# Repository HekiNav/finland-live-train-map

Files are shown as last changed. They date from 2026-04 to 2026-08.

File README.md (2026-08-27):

# Finland live train map

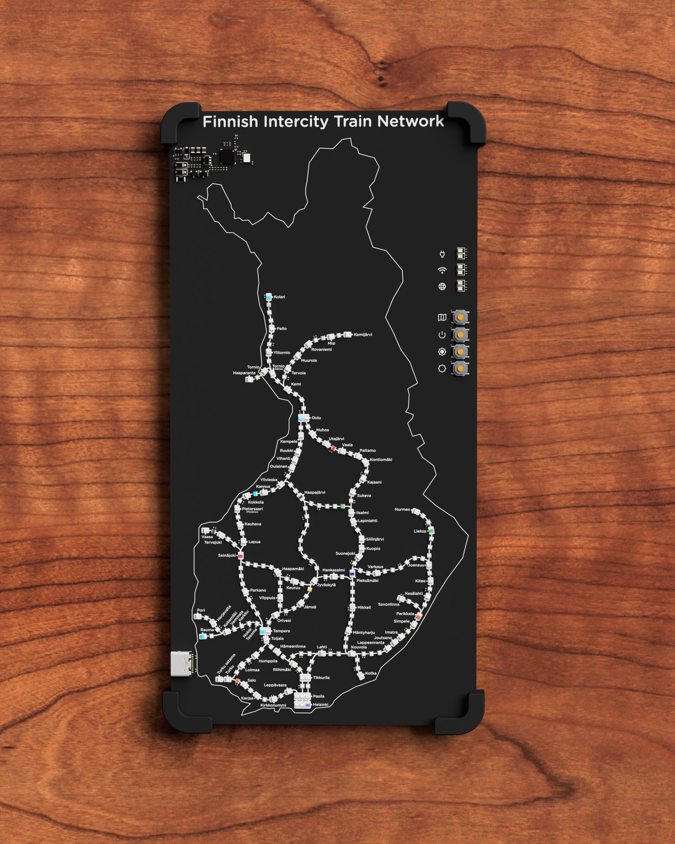
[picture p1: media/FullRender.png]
3dRender


The project consist of the physical pcb and case as well as the server that processes the information from the api and serves it to the ESP-32 to process. The physical project is a pcb with LEDs marking the route for intercity trains across Finland. There are two versions of the map. A more simplified version with just the routes visible. Then there is the more geografically correct version with the borders of Finland printed on the silkscreen. The LEDs mark the position of trains in real time so you can see at a glance where the trains are. The case makes it possible to wall mount the pcb or have it on your desk.

This project was made for Hack Club [Fallout](https://fallout.hackclub.com) by [NoseFa](https://github.com/NoseFa) and [Hekinav](https://github.com/HekiNav).

## Repository structure / table of contents

NOTE! All software has been moved to [another repo (HekiNav/ltm-firmware)](https://github.com/HekiNav/ltm-firmware)

**Each directory contains its own README file with more detailed information on the specific section. Basic information is provided here.**

### [`/pcb`](./pcb/README.md)
Contains KiCad design files
View interactive PCB design in [KiCanvas](https://kicanvas.org/?github=https%3A%2F%2Fgithub.com%2FHekinav%2FFinland-Live-Train-Map%2Ftree%2Fmain%2Fpcb)

### [`/design`](./design/README.md)
Contains Map Design ideas and plans as Inkscape SVGs

### [`/server`](https://github.com/HekiNav/ltm-firmware/tree/main/server/README.md)
Contains the NodeJS server that processes data from Fintraffic to amore usable format

### [`/firmware`](https://github.com/HekiNav/ltm-firmware/tree/main/firmware/README.md)
Contains the Platformio firmware for the ESP32C3

### [BuildGuide.md](BuildGuide.md)
Contains instructions for building the project.

## Why this exists

This project was made because we wanted to work on something together and Hack Club was running the Fallout event. Hekinav has built a similar type of project before for Helsinki. [The Helsinki Live Train map](https://github.com/HekiNav/helsinki-live-train-map) and we decided that making one of all the Trains in Finland would be cool. This project is meant to be something to look at and something cool to have in your space. Thats why we put so much effort in the silkscreen of the pcb and the placement of the LED's. We wanted it to be good to look at.

## BOM

The BOM for this project is pretty much just making buying the PCB and then 3d printing the case (we are self-printing so we didn't add this). You can see the JLCPCB formatted [BOM.csv](./pcb/jlcpcb/production_files/BOM-fin-ltm.csv). We have some more detailed information about how to order it. Here is also a table that just includes the price of the PCB and the assembly, shipping + customs for it.

| Part | Total price | Link | Extra info  | 
| --- | --- | --- | --- |
| PCB | 14.83€ | [JLCPCB](https://jlcpcb.com/pcb-fabrication/fr4-pcb)| |
| PCBA inc. components  | 136.03€ | [JLCPCB PCBA](https://jlcpcb.com/pcb-assembly) | For specific component pricing see the JLCPCB bom in the pcb folder  |
| JLCPCB shipping | 22.37€ | [Shipping](https://jlcpcb.com/shipping) | |
| Taxes / customs fees  | 44.18€ | [Tulli.fi](https://tulli.fi/tullilaskuri#/) | |
| | | | |
| Total | 217.42€ | | |

## Zine page

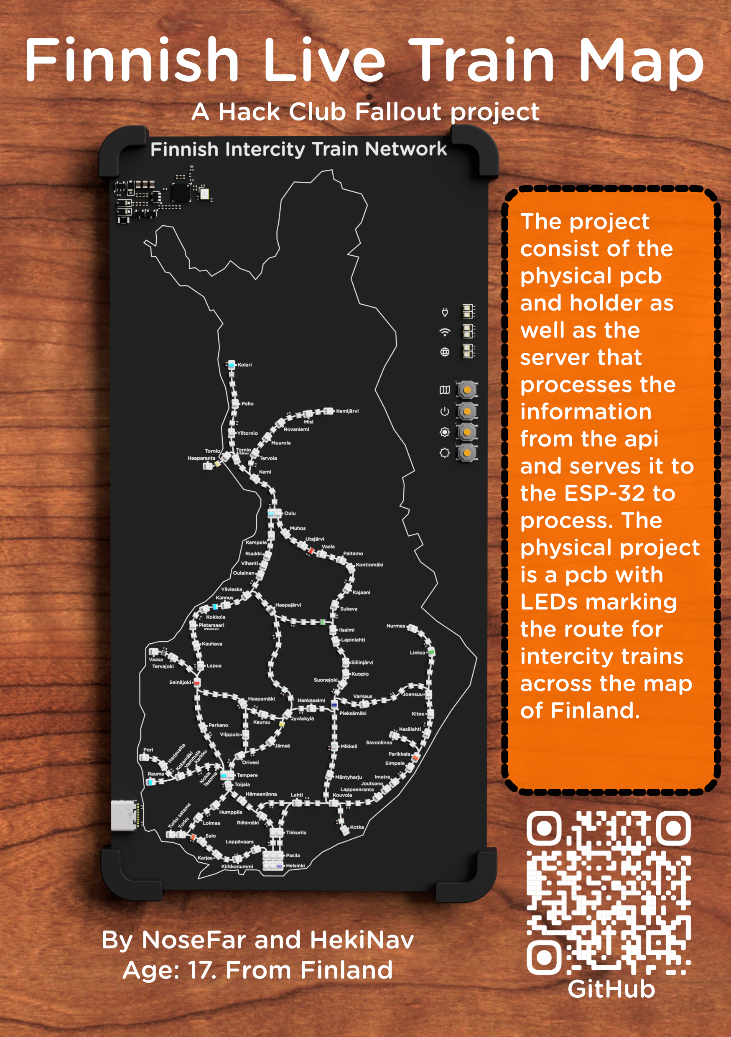
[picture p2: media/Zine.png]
Zine Page


We were required to make a Zine page for Fallout. Available as a [`zine.pdf`](Zine.pdf)

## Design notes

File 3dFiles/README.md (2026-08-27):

# 3D design

This section includes all the 3D models for the project. Including files for the full 3d project, ready to print files and the 3d files for the PCB. The [`/printable`](./Printable/) folder includes ready to print files and the [`/FullProject`](./FullProject/) folder includes the full Fusion project files including the PCB, holder etc.

## Design choices

We wanted the holder to be as simple as possible and not take away from the main piece which is the PCB and the map on it. We wanted the holder to cover as little as possible while still being secure and holding the PCB well. We also didn't want any screws on the pcb at all so the case was designed to fit these criteria. The PCB is held in slots and no screws are used. On the front side the holder only covers small areas in each corner so the PCB stays very visible. We also plan to print it in a black filament which makes it blend in with the PCB better. Currently there is a wall mounted version that has a similar hole that is used for mounting picture frames on the wall. 

3dRender

The case is printed in 3 seperate pieces. The main body and then the top corners that are seperate pieces that slot into the main frame when mounting. So print the main frame in one piece and then slot in the PCB to it and then finally add the top corners to make the holder more secure and look better. 

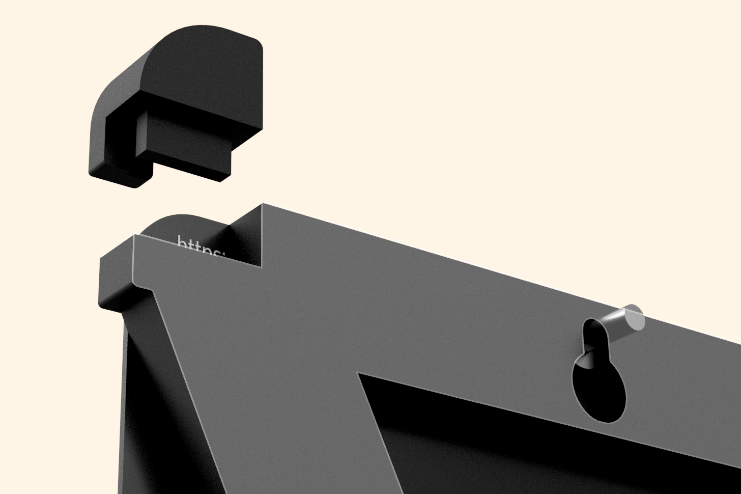
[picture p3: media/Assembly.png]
render assembly


Here is a picture of the frame seperated. 

## The kickstand

The full fusion project includes a lot of random history and a kickstanc section. This is because we were planning on adding a kickstand to the design but ended up not having time for it. The project history is kind of a mess because of this. The part does work and is done but the kickstand will be included in a later design version.

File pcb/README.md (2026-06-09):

[Back to main page](https://github.com/HekiNav/finland-live-train-map/tree/main)
# PCB Design

- Made in KiCad with [CDFER's JLCPCB KiCad library](https://github.com/CDFER/JLCPCB-Kicad-Library).
- Inspiration for antenna and power system taken from [CDFER's live train maps](https://keastudios.co.nz). They are very cool!
- Designed to be fabricated and assembled by JLCPCB
    - PCBA by JLC because tiny components and hundreds of leds are hard to assemble manually. Also, LCSC components are very cheap with JLC.

## Main components

- ESP32-C3FH4 (chip)
    - 4MiB built-in flash
- Level Shifter (3V3 data from esp to 5V led data)
    - [TI SN74LV1T34DBVR](https://www.lcsc.com/product-detail/C100024.html)
- Power management
    - USB VBUS to 5V and 3V3 rails
    - Mosfet to shut down 5V rail
- 239 ARGB LEDs: [Xinglight XL-1615RGBC-2812B-S](https://www.lcsc.com/product-detail/C41413180.html)
    - The -S version is less bright and cheaper than the non -S version. 
    - These LEDs are a cheaper alternative (knockoff) to WorldSemi WS2812Bs

### KiCanvas viewer

View interactive PCB design in [KiCanvas](https://kicanvas.org/?github=https%3A%2F%2Fgithub.com%2FHekinav%2FFinland-Live-Train-Map%2Ftree%2Fmain%2Fpcb)

**NOTICE**: KiCanvas does not properly render everything, plase hide layers User.1-User.5 to view power circuitry

## Schematic

Schematic image

Some of the LEDs are missing because they were removed after making the initial layout
Schematic image

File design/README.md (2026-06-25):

[Back to main page](https://github.com/HekiNav/finland-live-train-map/tree/main)

# Map layout design

The layout of the map can be geographical or graphical
The SVGs in this directory are Inkscape SVGs

## Two options for map

### Geographical

`GeographicalMap.svg`

- Geographically accurate
- Recognisable
- Some distances between stations very short/long

### Graphical

`graph_v1.svg`

- More compact, saves on PCB costs
- Distances between stations more equal.

## Techical design

`TrainMapSignal.svg`

- Technical design and plans

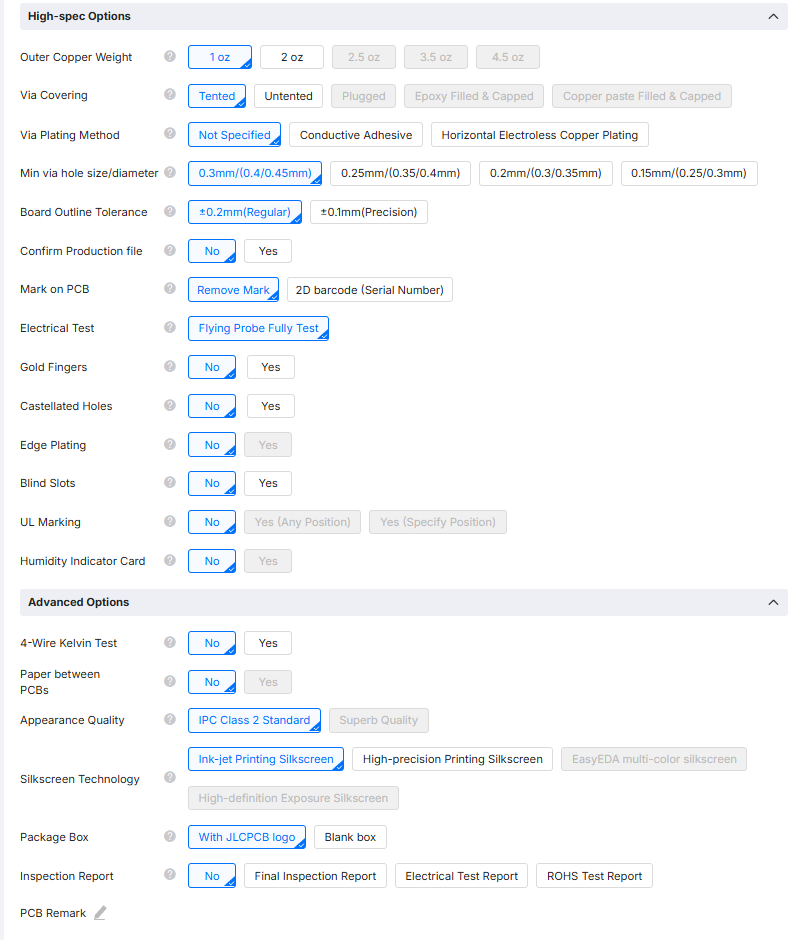
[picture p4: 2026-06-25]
media/JLCPCB/HighSpecOptions.png

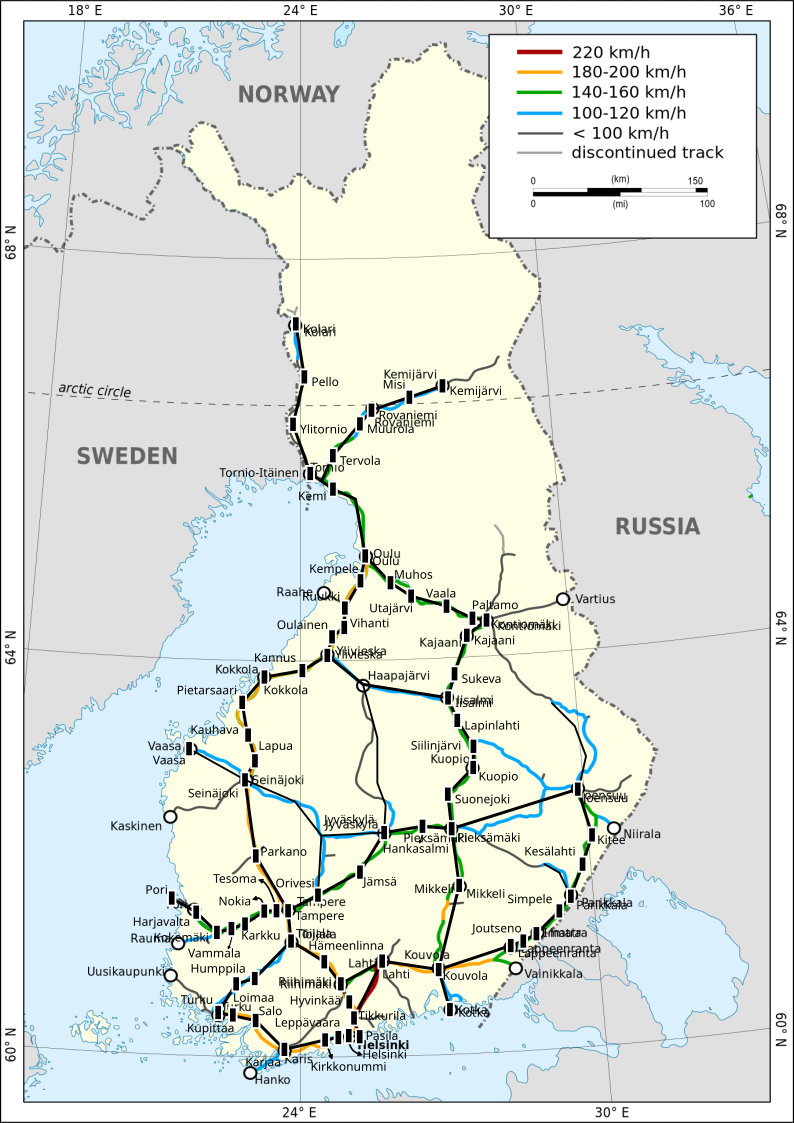
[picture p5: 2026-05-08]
design/GeographicalMap.png

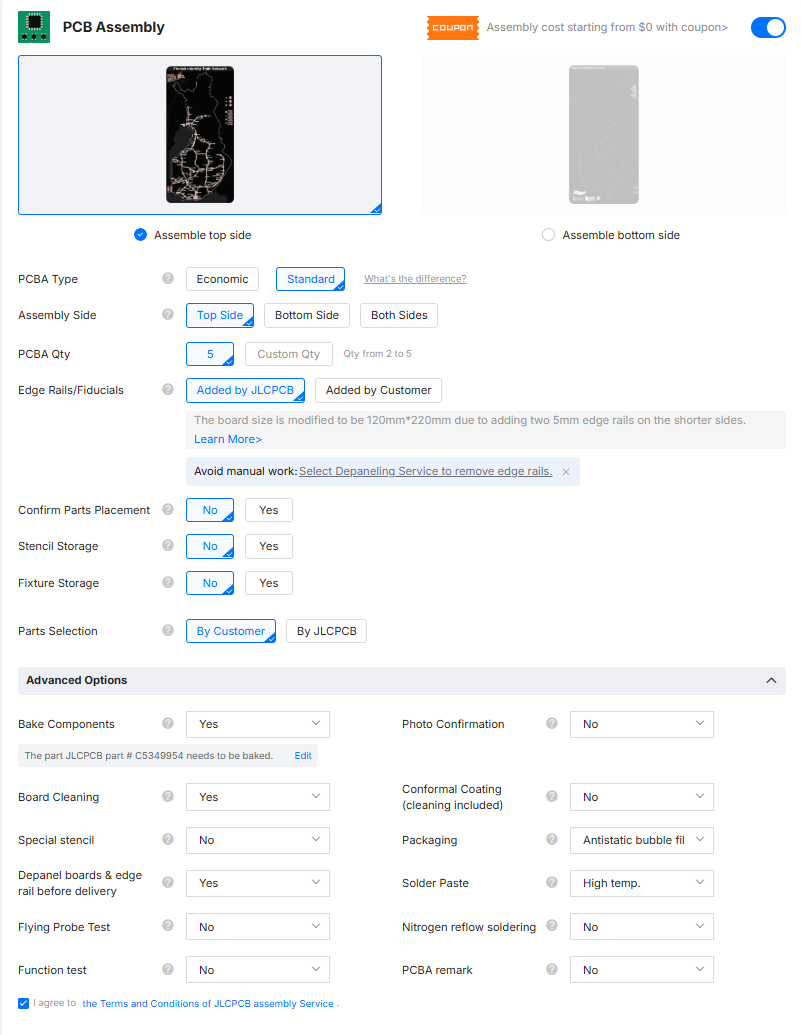
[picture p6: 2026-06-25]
media/JLCPCB/PCBAoptions.png

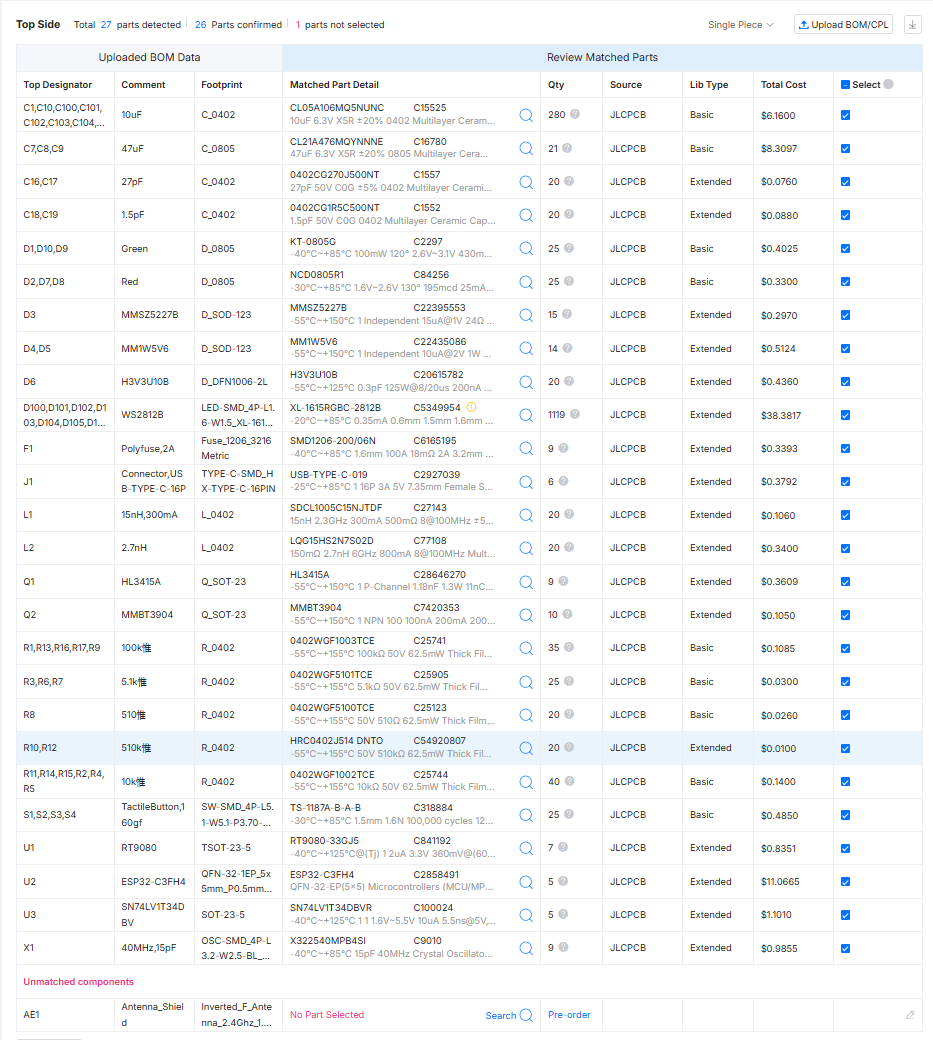
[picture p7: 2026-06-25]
media/JLCPCB/BOMOptions.png

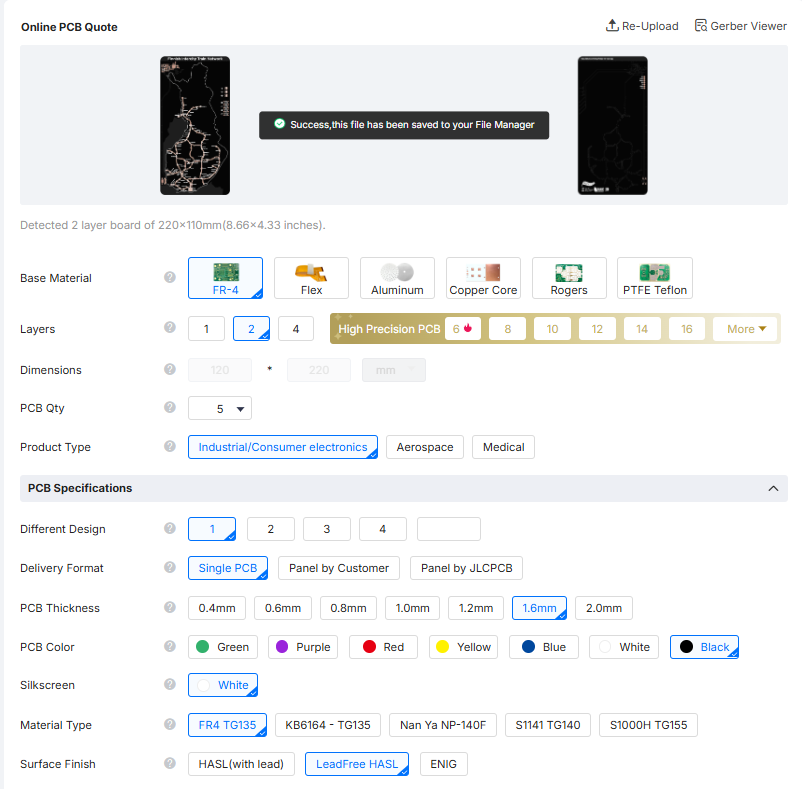
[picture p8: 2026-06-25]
media/JLCPCB/BasicPcbOptions.png

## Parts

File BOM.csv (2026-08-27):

Part | Quantity | Total price | Links | Extra info | LCSC id
PCB | 5 | 14.84€ | https://jlcpcb.com/pcb-fabrication/fr4-pcb
PCBA inc. components | 5 | 136.03€ | https://jlcpcb.com/pcb-assembly | For specific component pricing see the JLCPCB bom in the pcb folder
JLCPCB shipping (UPS) | 1 | 22.37€ | https://jlcpcb.com/shipping
Import tax / customs | 1 | 44.18€ | https://tulli.fi/tullilaskuri#/
1.5pF | 20 | 0.18€ | https://jlcpcb.com/partdetail/1904-0402CG1R5C500NT/C1552 |  | C1552
100kΩ | 35 | 0.11€ | https://jlcpcb.com/partdetail/26484-0402WGF1003TCE/C25741 |  | C25741
10kΩ | 40 | 0.14€ | https://jlcpcb.com/partdetail/26487-0402WGF1002TCE/C25744 |  | C25744
10uF | 280 | 9.97€ | https://jlcpcb.com/partdetail/16204-CL05A106MQ5NUNC/C15525 |  | C15525
15nH,300mA | 20 | 0.11€ | https://jlcpcb.com/partdetail/Sunlord-SDCL1005C15NJTDF/C27143 |  | C27143
2.7nH | 20 | 0.30€ | https://jlcpcb.com/partdetail/MurataElectronics-LQG15HS2N7S02D/C77108 |  | C77108
27pF | 20 | 0.09€ | https://jlcpcb.com/partdetail/1909-0402CG270J500NT/C1557 |  | C1557
40MHz, 15pF | 9 | 0.86€ | https://jlcpcb.com/partdetail/YXC_CrystalOscillators-X322540MPB4SI/C9010 |  | C9010
47uF | 21 | 3.67€ | https://jlcpcb.com/partdetail/17464-CL21A476MQYNNNE/C16780 |  | C16780
5.1kΩ | 25 | 0.03€ | https://jlcpcb.com/partdetail/26648-0402WGF5101TCE/C25905 |  | C25905
510kΩ | 20 | 0.01€ | https://jlcpcb.com/partdetail/HWACHN-HRC0402J514DNTO/C54920807 |  | C54920807
510Ω | 20 | 0.04€ | https://jlcpcb.com/parts/componentSearch?searchTxt=C25123 |  | C25123
Connector, USB-TYPE-C-16P | 6 | 0.33€ | https://jlcpcb.com/partdetail/DEALON-USB_TYPE_C019/C2927039 |  | C2927039
ESP32-C3FH4 | 5 | 9.44€ | https://jlcpcb.com/parts/componentSearch?searchTxt=C2858491 |  | C2858491
Discrete Diode Emerald Green Water Clear 0805 LED Indication | 25 | 0.35€ | https://jlcpcb.com/parts/componentSearch?searchTxt=C2297 |  | C2297
H3V3U10B | 20 | 0.60€ | https://jlcpcb.com/partdetail/hongjiacheng-H3V3U10B/C20615782 |  | C20615782
HL3415A | 9 | 0.32€ | https://jlcpcb.com/partdetail/hongjiacheng-HL3415A/C28646270 |  | C28646270
MM1W5V6 | 14 | 0.68€ | https://jlcpcb.com/partdetail/hongjiacheng-MM1W5V6/C22435086 |  | C22435086
MMBT3904 | 10 | 0.10€ | https://jlcpcb.com/partdetail/hongjiacheng-MMBT3904/C7420353 |  | C7420353
MMSZ5227B | 15 | 0.26€ | https://jlcpcb.com/partdetail/hongjiacheng-MMSZ5227B/C22395553 |  | C22395553
Polyfuse, 2A | 9 | 0.32€ | https://jlcpcb.com/partdetail/BORN-SMD1206_20006N/C6165195 |  | C6165195
Red | 25 | 0.29€ | https://jlcpcb.com/partdetail/85425-NCD0805R1/C84256 |  | C84256
SN74LV1T34DBV | 5 | 0.95€ | https://jlcpcb.com/partdetail/TexasInstruments-SN74LV1T34DBVR/C100024 |  | C100024
Tactile Button, 160gf | 25 | 0.44€ | https://jlcpcb.com/partdetail/XKBConnection-TS_1187A_B_AB/C318884 |  | C318884
WS2812B | 1119 | 33.71€ | https://jlcpcb.com/partdetail/XINGLIGHT-XL_1615RGBC2812B/C5349954 |  | C5349954
RT9080 | 7 | 0.73€ | https://jlcpcb.com/partdetail/RichtekTech-RT908033GJ5/C841192 |  | C841192
Total: |  | 281.46€

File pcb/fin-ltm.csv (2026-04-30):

Reference | Qty | Value | DNP | Exclude from BOM | Exclude from Board | Footprint | Datasheet | Class | LCSC
AE1 | 1 | Antenna_Shield |  |  |  |  | ~
C1,C2,C3,C4,C5,C6,C7,C11,C12,C13,C18,C19,C20,C21,C22 | 15 | 10uF |  |  |  | PCM_JLCPCB:C_0402 | https://www.lcsc.com/datasheet/lcsc_datasheet_2208231630_Samsung-Electro-Mechanics-CL05A106MQ5NUNC_C15525.pdf | Basic Component | C15525
C8,C9,C10 | 3 | 47uF |  |  |  | PCM_JLCPCB:C_0805 | https://www.lcsc.com/datasheet/lcsc_datasheet_2304140030_Samsung-Electro-Mechanics-CL21A476MQYNNNE_C16780.pdf | Basic Component | C16780
C14,C15 | 2 | 27pF |  |  |  | PCM_JLCPCB:C_0402 | https://www.lcsc.com/datasheet/lcsc_datasheet_2304140030_FH--Guangdong-Fenghua-Advanced-Tech-0402CG270J500NT_C1557.pdf | Preferred Component | C1557
C16,C17 | 2 | 1.5pF |  |  |  | PCM_JLCPCB:C_0402 | https://www.lcsc.com/datasheet/lcsc_datasheet_2304140030_FH--Guangdong-Fenghua-Advanced-Tech-0402CG1R5C500NT_C1552.pdf | Preferred Component | C1552
D1,D7,D9 | 3 | Red |  |  |  | PCM_JLCPCB:D_0805 | https://www.lcsc.com/datasheet/lcsc_datasheet_2409272203_Foshan-NationStar-Optoelectronics-NCD0805R1_C84256.pdf | Basic Component | C84256
D2,D4 | 2 | MM1W5V6 |  |  |  | PCM_JLCPCB:D_SOD-123 | https://wmsc.lcsc.com/wmsc/upload/file/pdf/v2/lcsc/2405210914_hongjiacheng-MM1W5V6_C22435086.pdf | Preferred Component | C22435086
D3 | 1 | MMSZ5227B |  |  |  | PCM_JLCPCB:D_SOD-123 | https://wmsc.lcsc.com/wmsc/upload/file/pdf/v2/lcsc/2405091603_hongjiacheng-MMSZ5227B_C22395553.pdf | Preferred Component | C22395553
D5,D8,D10 | 3 | Green |  |  |  | PCM_JLCPCB:D_0805 | https://www.lcsc.com/datasheet/lcsc_datasheet_1806151820_Hubei-KENTO-Elec-KT-0805G_C2297.pdf | Basic Component | C2297
D6 | 1 | H3V3U10B |  |  |  | PCM_JLCPCB:D_DFN1006-2L | https://wmsc.lcsc.com/wmsc/upload/file/pdf/v2/lcsc/2401261524_hongjiacheng-H3V3U10B_C20615782.pdf | Preferred Component | C20615782
F1 | 1 | Polyfuse, 2A |  |  |  | Fuse:Fuse_1206_3216Metric | ~ |  | C6165195
J1 | 1 | Connector, USB-TYPE-C-16P |  |  |  | PCM_JLCPCB:TYPE-C-SMD_HX-TYPE-C-16PIN | https://atta.szlcsc.com/upload/public/pdf/source/20220920/0EF8F885FCCEA71F60E9E85152155021.pdf |  | C2927039
J2 | 1 | Test Connector |  | Excluded from BOM
J3 | 1 | Display |  | Excluded from BOM
L1 | 1 | 15nH,300mA |  |  |  | PCM_JLCPCB:L_0402 | https://www.lcsc.com/datasheet/lcsc_datasheet_2310301641_Sunlord-SDCL1005C15NJTDF_C27143.pdf | Preferred Component | C27143
L2 | 1 | 2.7nH |  |  |  | PCM_JLCPCB:L_0402 | ~ |  | C77108
Q1 | 1 | MMBT3904 |  |  |  | PCM_JLCPCB:Q_SOT-23 | https://wmsc.lcsc.com/wmsc/upload/file/pdf/v2/lcsc/2312221203_hongjiacheng-MMBT3904_C7420353.pdf | Preferred Component | C7420353
Q2 | 1 | HL3415A |  |  |  | PCM_JLCPCB:Q_SOT-23 | https://wmsc.lcsc.com/wmsc/upload/file/pdf/v2/lcsc/2407121622_hongjiacheng-HL3415A_C28646270.pdf | Preferred Component | C28646270
R1,R2,R10 | 3 | 5.1kΩ |  |  |  | PCM_JLCPCB:R_0402 | https://www.lcsc.com/datasheet/lcsc_datasheet_2206010045_UNI-ROYAL-Uniroyal-Elec-0402WGF5101TCE_C25905.pdf | Basic Component | C25905
R3,R5,R9,R12,R14,R16,R17,R18,R19 | 9 | 10kΩ |  |  |  | PCM_JLCPCB:R_0402 | https://www.lcsc.com/datasheet/lcsc_datasheet_2411221126_UNI-ROYAL-Uniroyal-Elec-0402WGF1002TCE_C25744.pdf | Basic Component | C25744
R4,R8 | 2 | 510kΩ |  |  |  | PCM_JLCPCB:R_0402 | https://www.lcsc.com/datasheet/lcsc_datasheet_2206010216_UNI-ROYAL-Uniroyal-Elec-0402WGF5103TCE_C11616.pdf | Preferred Component | C11616
R6,R7,R13,R15 | 4 | 100kΩ |  |  |  | PCM_JLCPCB:R_0402 | https://www.lcsc.com/datasheet/lcsc_datasheet_2206010100_UNI-ROYAL-Uniroyal-Elec-0402WGF1003TCE_C25741.pdf | Basic Component | C25741
R11 | 1 | 510Ω |  |  |  | PCM_JLCPCB:R_0402 | https://www.lcsc.com/datasheet/lcsc_datasheet_2205311900_UNI-ROYAL-Uniroyal-Elec-0402WGF5100TCE_C25123.pdf | Basic Component | C25123
S1,S2,S3,S4 | 4 | Tactile Button, 160gf |  |  |  | PCM_JLCPCB:SW-SMD_4P-L5.1-W5.1-P3.70-LS6.5-TL-2 | https://www.lcsc.com/datasheet/lcsc_datasheet_2304140030_XKB-Connection-TS-1187A-B-A-B_C318884.pdf | Basic Component | C318884
U1 | 1 | ESP32-C3FH4 |  |  |  | PCM_JLCPCB:QFN-32-1EP_5x5mm_P0.5mm_EP3.7x3.7mm_ThermalVias | https://www.espressif.com/sites/default/files/documentation/esp32-c3_datasheet_en.pdf |  | C2858491
U2 | 1 | RT9080 |  |  |  | Package_TO_SOT_SMD:TSOT-23-5 |  |  | C841192
U3 | 1 | SN74LV1T34DBV |  |  |  | Package_TO_SOT_SMD:SOT-23-5 | https://www.ti.com/lit/ds/symlink/sn74lv1t34.pdf |  | C100024
X1 | 1 | 40MHz, 15pF |  |  |  | PCM_JLCPCB:OSC-SMD_4P-L3.2-W2.5-BL_SIT8008BI | https://www.lcsc.com/datasheet/lcsc_datasheet_2403291504_YXC-Crystal-Oscillators-X322540MPB4SI_C9010.pdf |  | C9010

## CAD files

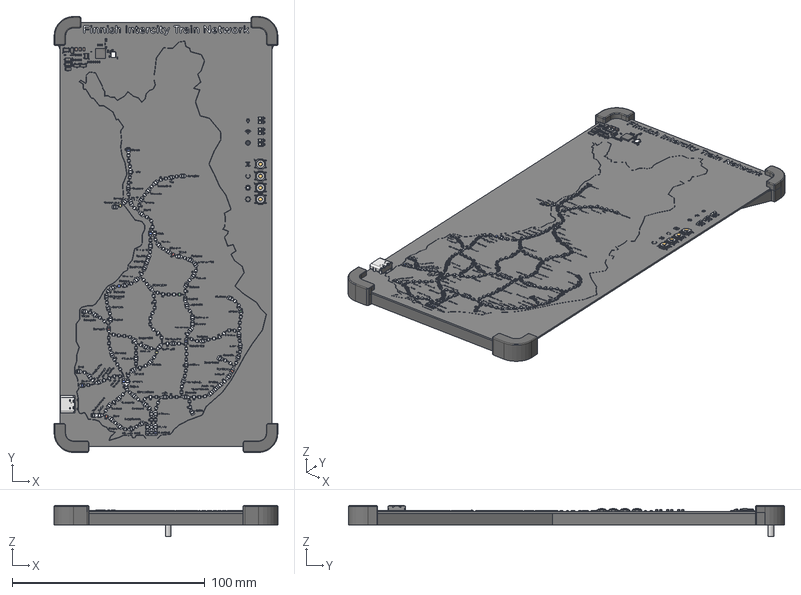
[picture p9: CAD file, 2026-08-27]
3dFiles/FullProject/FullProject.step
116.0 x 226.0 x 16.1 mm
零件26 x 223
R_0402_1005Metric x 17
C_0402_1005Metric x 58
SW_SPST_TL3342 x 4
LED_0805_2012Metric_Castellated x 6
Fuse_1206_3216Metric_1
SOT_23 x 2
C_0805_2012Metric x 3
QFN-32-1EP_5x5mm_Pitch0.5mm
D_SOD_123 x 3
OSC-SMD_4P-L3.2-W2.5-CJ13-320001210A20
DFN1006_L1-W0.6-H0.4-2L-RD
TYPE-C-SMD_HX-TYPE-C-16PIN_1
L_0402_1005Metric x 2
SOT-23-5_1
TSOT-23-5_1
fin-ltm_silkscreen
fin-ltm_silkscreen_1
fin-ltm_PCB
FinnishTrainProject
BHS JIS B 1111 - M3x8 Steel 4.6 Plain

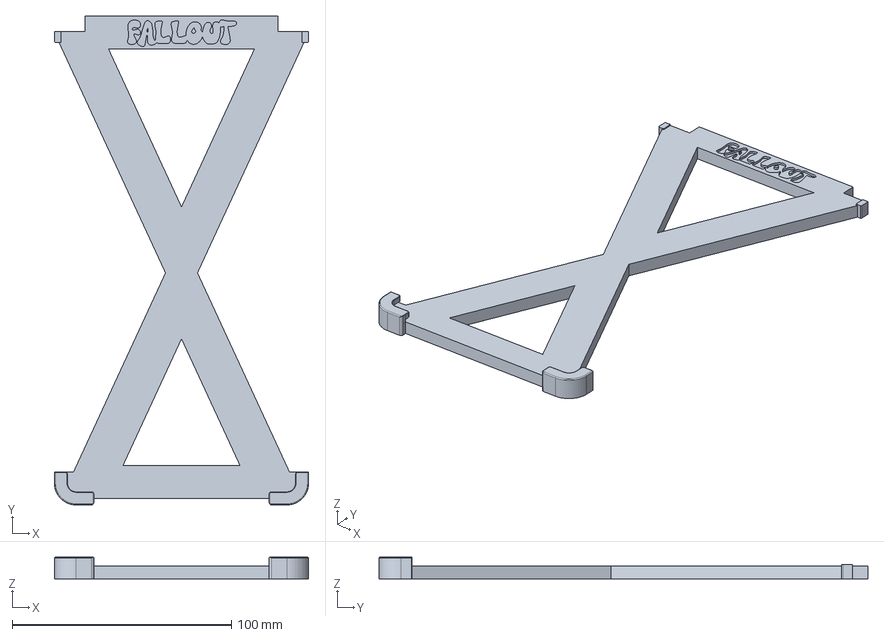
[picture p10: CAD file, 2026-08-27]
3dFiles/Printable/WallMount/WallmountMainBody.step
116.0 x 223.0 x 10.0 mm

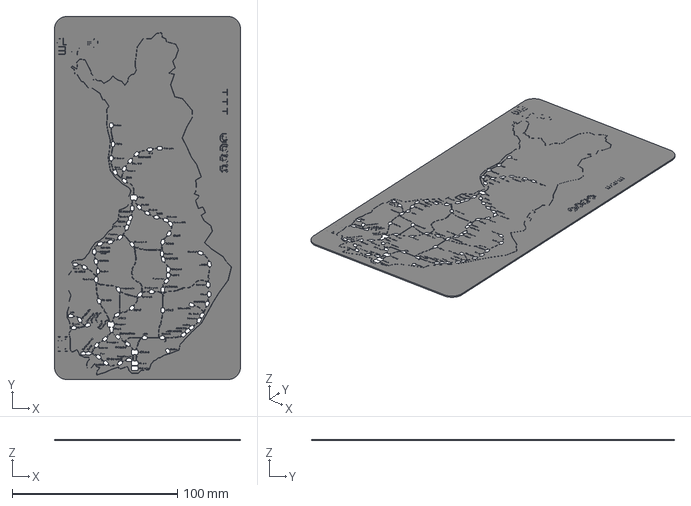
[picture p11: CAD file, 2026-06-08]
3dFiles/PCB/OnlyPcb.step
112.5 x 219.5 x 0.975 mm
fin-ltm_silkscreen x 2
fin-ltm_PCB

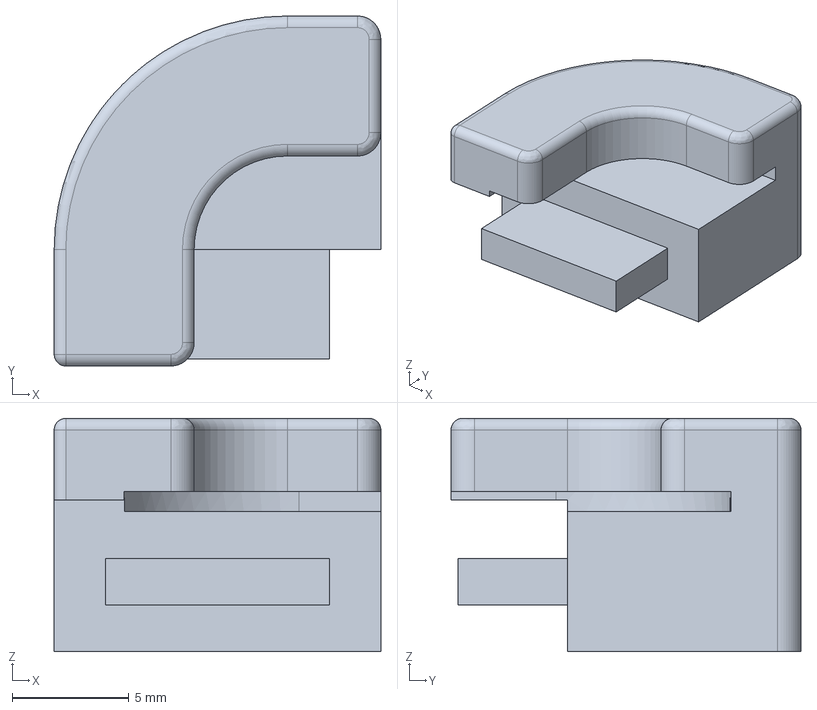
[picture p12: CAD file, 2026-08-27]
3dFiles/Printable/WallMount/WallMountTopLeft.step
14.0 x 15.0 x 10.0 mm

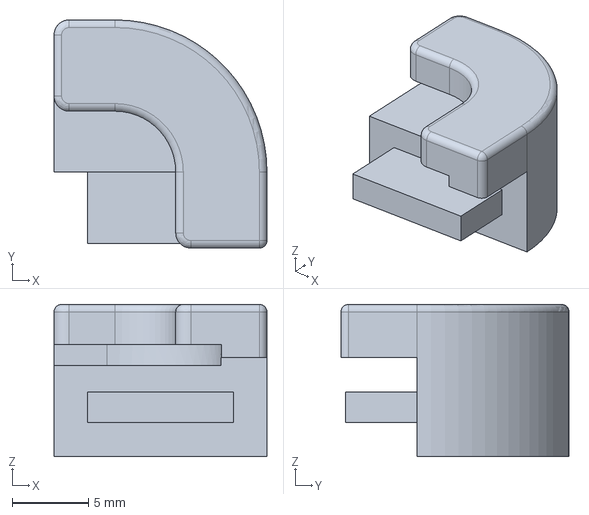
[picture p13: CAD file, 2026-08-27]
3dFiles/Printable/WallMount/WallMountTopRight.step
14.0 x 15.0 x 10.0 mm

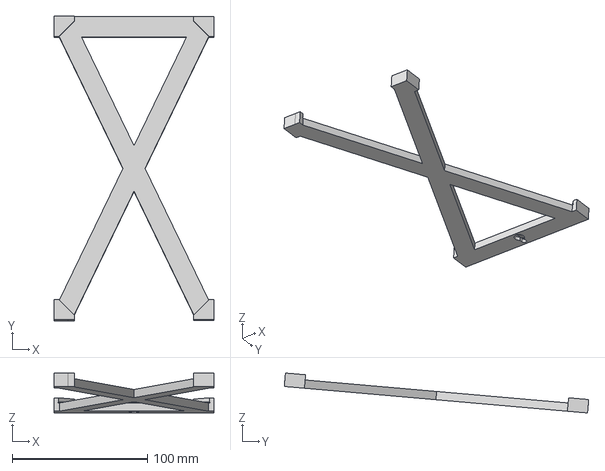
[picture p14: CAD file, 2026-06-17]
3dFiles/Printable/WallMount/PCBWallMount.step
118.5 x 225.5 x 29.6 mm

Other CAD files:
3dFiles/Blender render/pcb.blend
3dFiles/Printable/WallMount/PCBWallMount.3mf
3dFiles/Printable/WallMount/WallMountMainBody.3mf
3dFiles/Printable/WallMount/WallMountTopLeft.3mf
3dFiles/Printable/WallMount/WallMountTopRight.3mf

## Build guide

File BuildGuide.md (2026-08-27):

# Build guide

We will go over part ordering and then hands on assembly.

## Ordering PCB

The PCB is the most expensive part of this project and can cost upwards of 200$ depending on shipping cost and manufacturer. It's ordered from a manufacturer like [JLCPCB](https://jlcpcb.com/). You should order the PCB assembled so as a PCBA. We ordered from [JLCPCB](https://jlcpcb.com/) and made ready to use files in the [jlcpcb folder](./pcb/jlcpcb/). The production files folder includes ready zip files, bom and clp files that can just be added when ordering. We also included the gerber files in non zip format  in the [`/pcb/jlcpcb/gerber`](./pcb/jlcpcb/gerber/) folder. There is a minimum order amount of 5 so you will most likely have to order extra if you want to make this project.

Here are somethings to keep in mind when ordering from JLCPCB/what options we selected for the order.

* We ordered the pcb in black with a white silkscreen.
* Lead free HASL
* Standard PCBA (required because of the amount of LEDs)
* Assembly side: top
* Bake components selected because the JLCPCB part #C5349954 needs to be baked.
* Board cleaning: yes
* Depanel boards & edge rail before delivery: yes
* Antenna shows up as a component in the BOM but it doesn't have to be selected as a component and is okay to be left as empty.
* The R10 and R12 parts that were mapped to the C11616 part were on shortfall so we replaced them with the C54920807 part.

Other options were left as defaults / not edited. If you want to check you have the same options you can see the [`/media/JLCPCB`](./media/JLCPCB/). Where there are screenshots of the order process.

## Ordering / printing the holder

Technically this project doesn't require a holder but if you want to hang this on the wall or having it stand on a desk you will need one. The wall mount is designed to be printed with minimal supports. It has slots for the PCB to slide into and it has a keyhole for mounting to the wall like a picture frame. You can either print this by yourself if you have a 3d printer or use a service like [JLC3DP](https://jlc3dp.com/). We had a printer we could use so we printed the holder ourselve. If you want more info about the design choices etc. for the holder check the [`/3dfiles`](./3dFiles/README.md) folder.

## Flashing the firmware

Connect your board via the USB Type-C port to a computer. It is recommended to use the Web Installer but building from source is also easy

### Web Installer

Go to [the Web Installer site](https://ltm.hekinav.dev/web_installer/) and follow the instructions on the site.

### Building from source

Use the guide in the [firmware repo](https://github.com/hekinav/ltm-firmware/tree/main/firmware#compiling-the-code-yourself)

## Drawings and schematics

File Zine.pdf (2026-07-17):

# Finnish Live Train Map

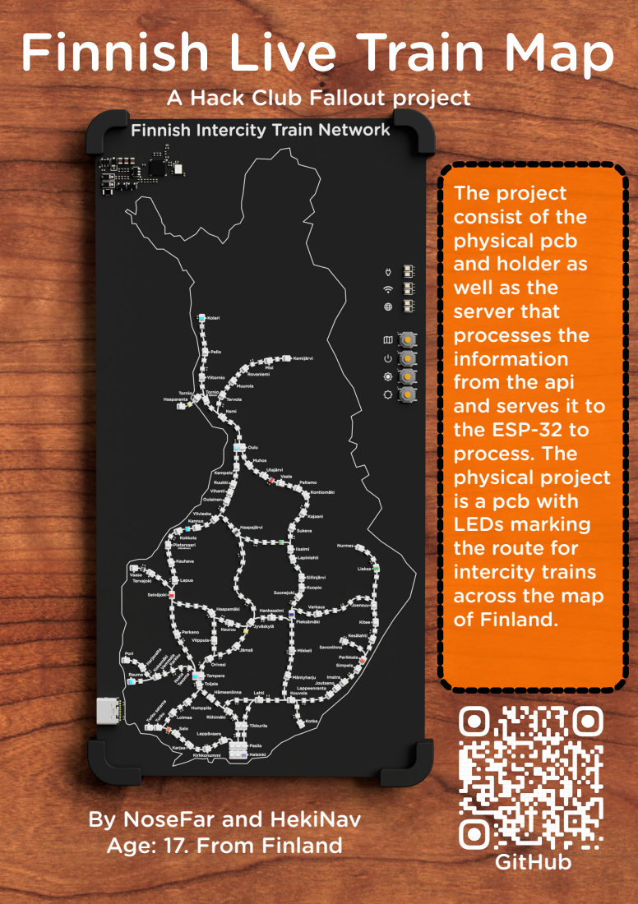
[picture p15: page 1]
GitHub

A Hack Club Fallout project

The project
consist of the
physical pcb
and holder as
well as the
server that
processes the
information
from the api
and serves it to
the ESP-32 to
process. The
physical project
is a pcb with
LEDs marking
the route for
intercity trains
across the map
of Finland.

By NoseFar and HekiNav
Age: 17. From Finland

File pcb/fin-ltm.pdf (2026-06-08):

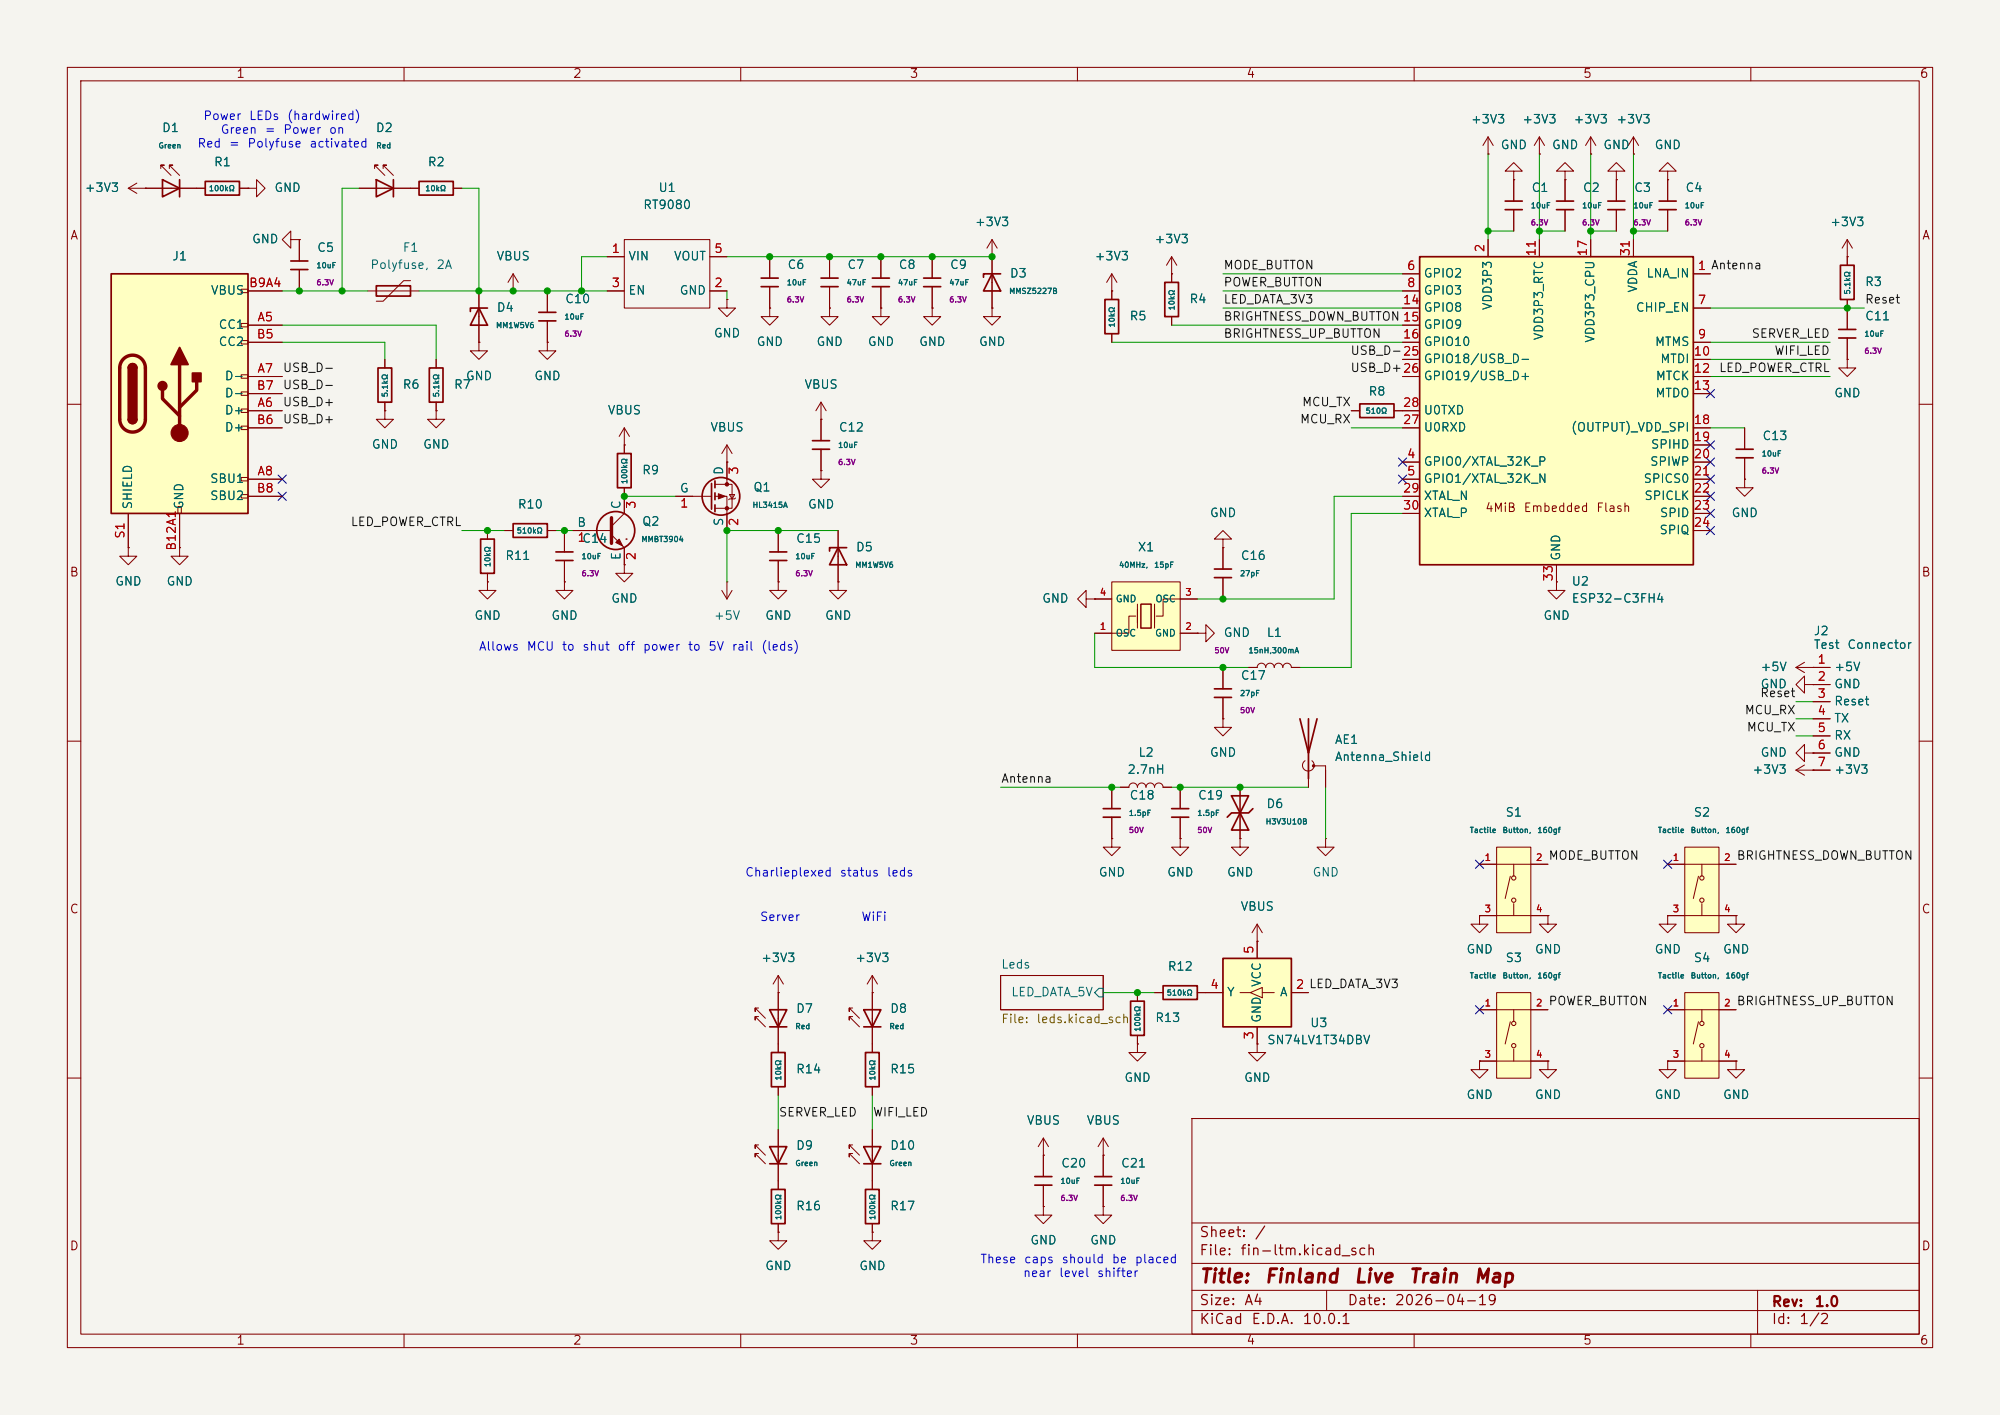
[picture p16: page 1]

Power LEDs (hardwired) Green = Power on Red = Polyfuse activated

2 GPIO0/XTAL_32K_P 4 GPIO1/XTAL_32K_N 5 GPIO2 6 CHIP_EN 7 GPIO3 8 MTMS 9 MTDI 10 VDD3P3_RTC 11 MTCK 12 MTDO 13 GPIO8 14 GPIO9 15 GPIO10 16 VDD3P3_CPU 17

Test Connector +5V 1 GND 2 Reset 3
GND +5V GND

Sheet: /
File: fin-ltm.kicad_sch
Title: Finland Live Train Map

Size: A4 | Rev: 1.0
KiCad E.D.A. 10.0.1 | Id: 1/2

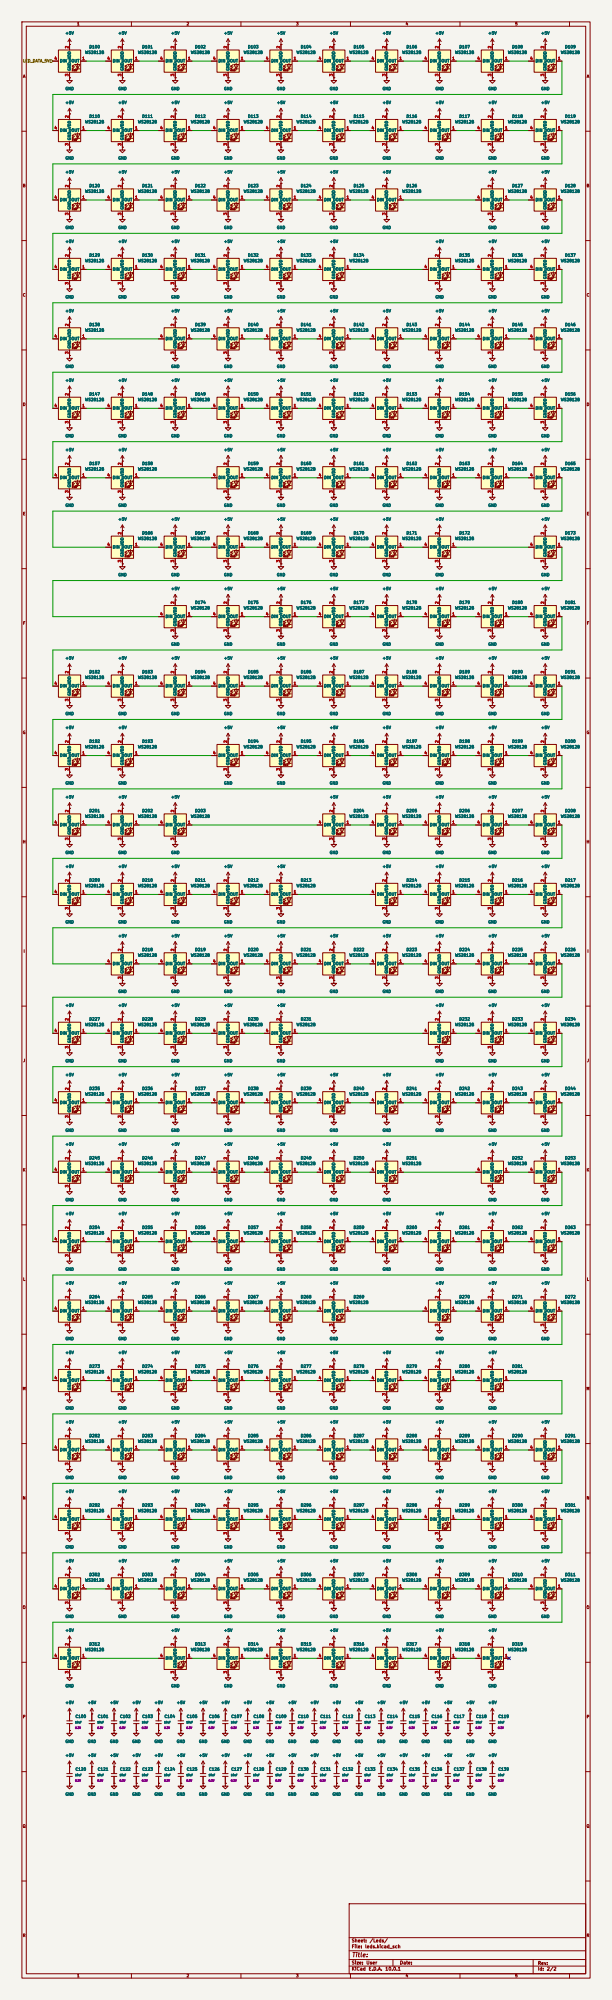
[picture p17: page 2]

3 DIN 4 D132 WS2812B +5V GND +5V +5V GND +5V GND

3 DIN 4 +5V GND +5V +5V GND +5V GND

3 DIN 4 D130 WS2812B +5V GND GND +5V GND

3 DIN 4 +5V GND GND +5V GND

3 DIN 4 GND +5V GND GND

3 DIN 4 GND GND GND +5V D165 WS2812B

3 DIN 4 GND +5V GND +5V GND +5V +5V +5V GND +5V D176 WS2812B

3 DIN 4 GND +5V GND +5V GND

3 DIN 4 GND +5V +5V GND +5V GND +5V +5V D208 WS2812B

3 DIN 4 +5V GND GND +5V +5V GND

3 DIN 4 GND GND +5V +5V +5V GND

3 DIN 4 GND +5V GND +5V GND GND +5V +5V +5V GND

3 DIN 4 GND +5V GND GND +5V +5V GND

Size: User | Rev:
KiCad E.D.A. 10.0.1 | Id: 2/2

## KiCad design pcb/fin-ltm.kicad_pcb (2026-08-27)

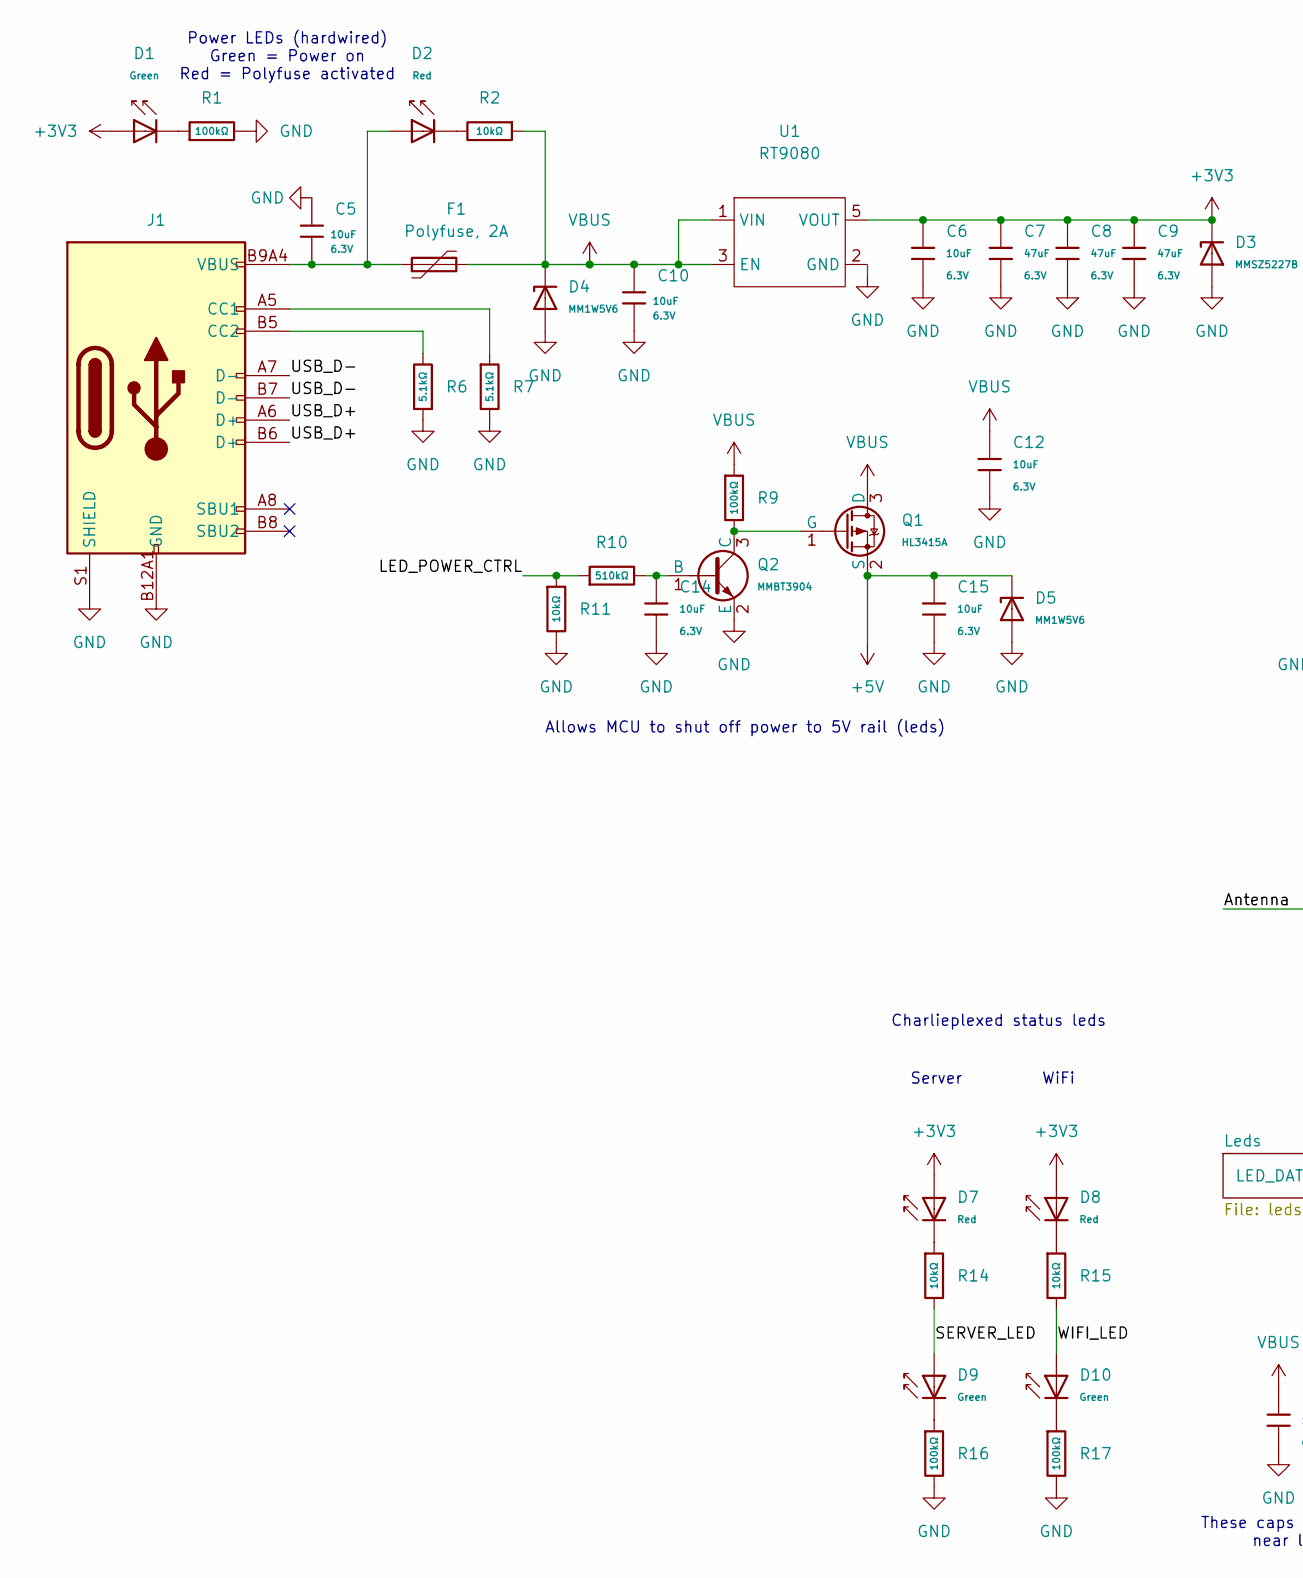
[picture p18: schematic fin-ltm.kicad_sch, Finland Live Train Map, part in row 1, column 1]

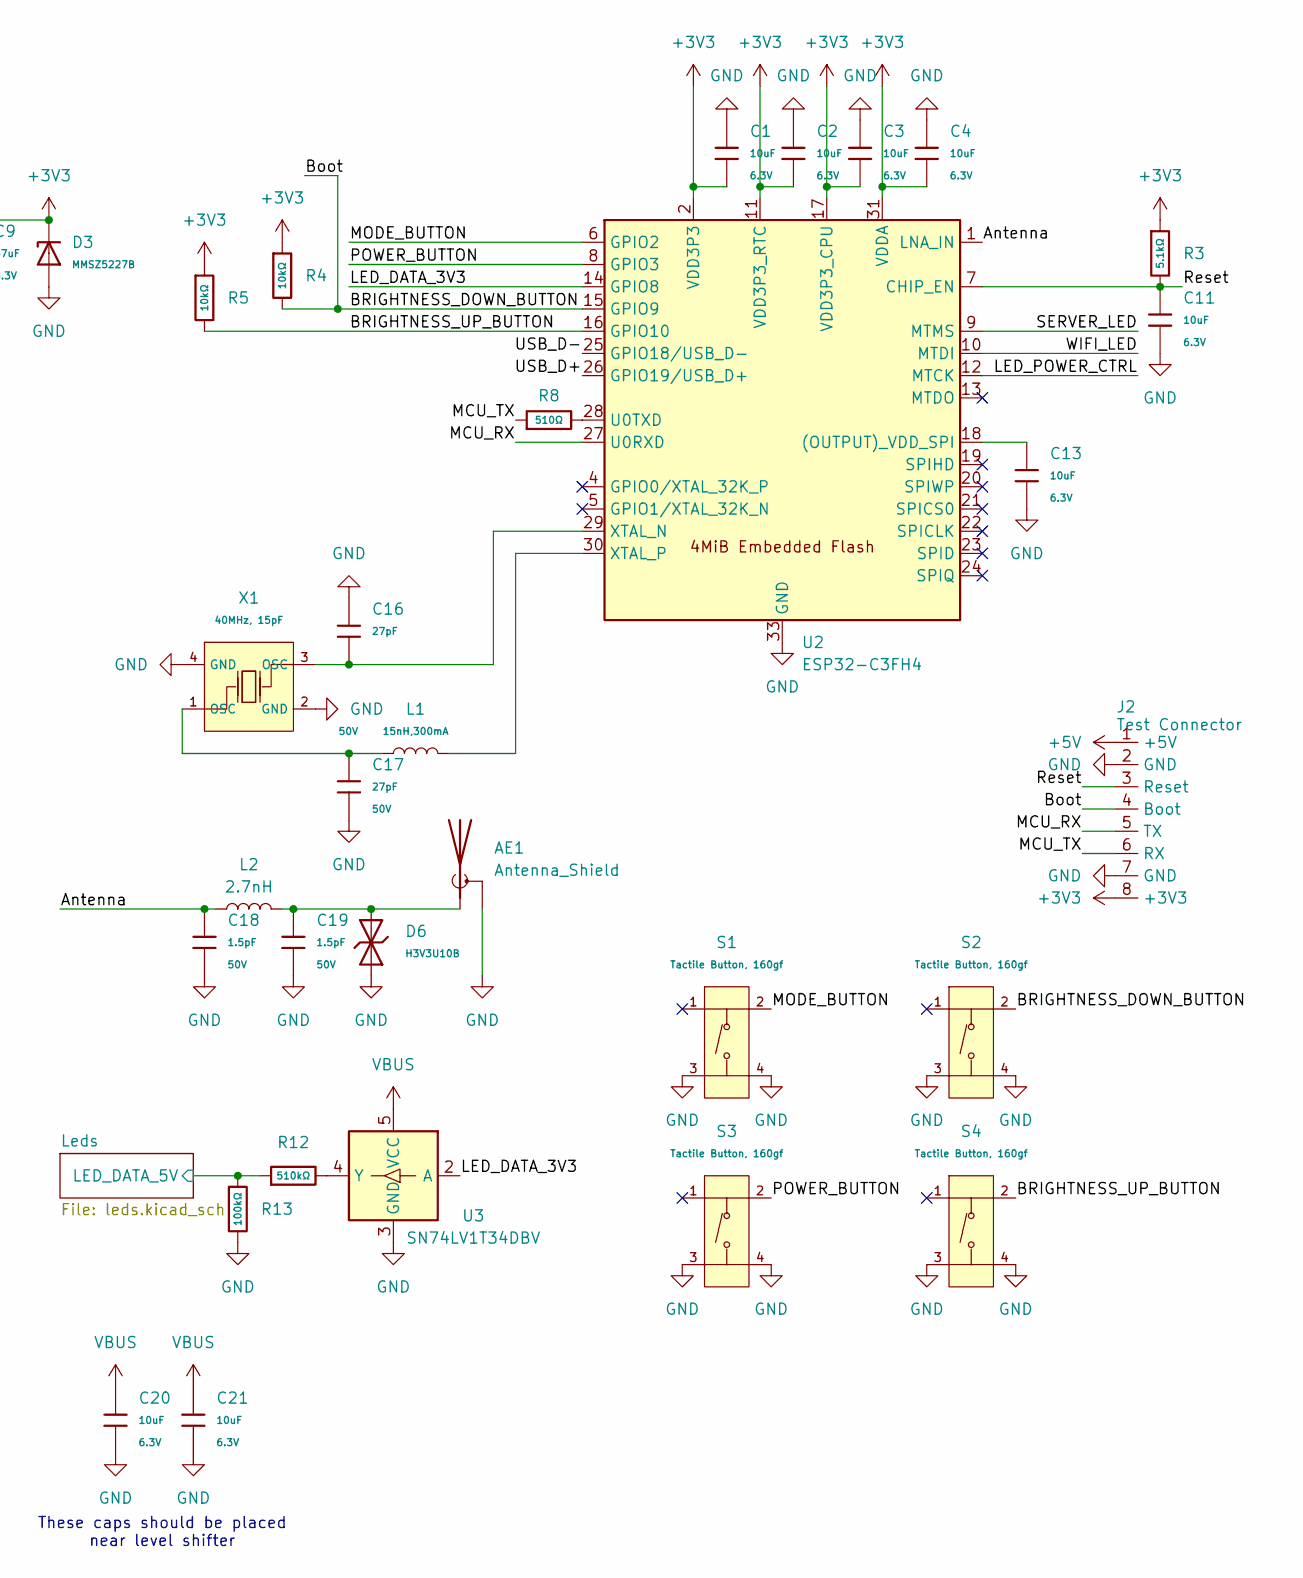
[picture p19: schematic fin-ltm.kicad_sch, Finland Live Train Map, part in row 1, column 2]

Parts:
AE1: Antenna_Shield; Inverted_F_Antenna_2.4Ghz_1.0mmPCB_TI_CC2430DB.pretty
C1, C2, C3, C4, C5, C6, C10, C11, C12, C13, C14, C15, C20, C21: 10uF; C_0402; Voltage Rated 6.3V; Tolerance ±20%; Part CL05A106MQ5NUNC; LCSC C15525
C7, C8, C9: 47uF; C_0805; Voltage Rated 6.3V; Tolerance ±20%; Part CL21A476MQYNNNE; LCSC C16780
C16, C17: 27pF; C_0402; Voltage Rated 50V; Tolerance ±5%; Part 0402CG270J500NT; LCSC C1557
C18, C19: 1.5pF; C_0402; Voltage Rated 50V; Part 0402CG1R5C500NT; LCSC C1552
D1, D9, D10: Green; D_0805; Part KT-0805G; LCSC C2297
D2, D7, D8: Red; D_0805; Forward Voltage (VF) 1.6V~2.6V; Part NCD0805R1; LCSC C84256
D3: MMSZ5227B; D_SOD-123; Part MMSZ5227B; LCSC C22395553
D4, D5: MM1W5V6; D_SOD-123; Part MM1W5V6; LCSC C22435086
D6: H3V3U10B; D_DFN1006-2L; Part H3V3U10B; LCSC C20615782
F1: Polyfuse, 2A; Fuse_1206_3216Metric; LCSC C6165195
J1: Connector, USB-TYPE-C-16P; TYPE-C-SMD_HX-TYPE-C-16PIN; LCSC C2927039
J2: Test Connector; Test_connector
L1: 15nH,300mA; L_0402; Tolerance ±5%; Part SDCL1005C15NJTDF; LCSC C27143
L2: 2.7nH; L_0402; LCSC C77108
Q1: HL3415A; Q_SOT-23; Part HL3415A; LCSC C28646270
Q2: MMBT3904; Q_SOT-23; Part MMBT3904; LCSC C7420353
R1, R9, R13, R16, R17: 100kΩ; R_0402; Overload Voltage (Max) 50V; Tolerance ±1%; Part 0402WGF1003TCE; LCSC C25741
R2, R4, R5, R11, R14, R15: 10kΩ; R_0402; Overload Voltage (Max) 50V; Tolerance ±1%; Part 0402WGF1002TCE; LCSC C25744
R3, R6, R7: 5.1kΩ; R_0402; Overload Voltage (Max) 50V; Tolerance ±1%; Part 0402WGF5101TCE; LCSC C25905
R8: 510Ω; R_0402; Overload Voltage (Max) 50V; Tolerance ±1%; Part 0402WGF5100TCE; LCSC C25123
R10, R12: 510kΩ; R_0402; Overload Voltage (Max) 50V; Tolerance ±1%; Part 0402WGF5103TCE; LCSC C11616
S1, S2, S3, S4: Tactile Button, 160gf; SW-SMD_4P-L5.1-W5.1-P3.70-LS6.5-TL-2; Voltage Rating (Dc) 12V; Part TS-1187A-B-A-B; LCSC C318884
U1: RT9080; TSOT-23-5; LCSC C841192
U2: ESP32-C3FH4; QFN-32-1EP_5x5mm_P0.5mm_EP3.7x3.7mm_ThermalVias; LCSC C2858491
U3: SN74LV1T34DBV; SOT-23-5; LCSC C100024
X1: 40MHz, 15pF; OSC-SMD_4P-L3.2-W2.5-BL_SIT8008BI; PartID X322540MPB4SI; LCSC C9010

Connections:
+3V3: C1.2, C2.2, C3.2, C4.2, C6.1, C7.1, C8.1, C9.1, D1.2, D3.1, D7.2, D8.2, J2.8 (+3V3), R3.1, R4.1, R5.1, U1.5 (VOUT), U2.2 (VDD3P3), U2.3 (VDD3P3), U2.11 (VDD3P3_RTC), U2.17 (VDD3P3_CPU), U2.31 (VDDA), U2.32 (VDDA)
+5V: C15.1, D5.1, J2.1 (+5V), Q1.2 (S); also elsewhere on the board
/Antenna: C18.1, L2.1, U2.1 (LNA_IN)
/BRIGHTNESS_DOWN_BUTTON: J2.4 (Boot), R4.2, S2.2 (B), U2.15 (GPIO9)
/BRIGHTNESS_UP_BUTTON: R5.2, S4.2 (B), U2.16 (GPIO10)
/LED_DATA_3V3: U2.14 (GPIO8), U3.2 (A)
/LED_POWER_CTRL: R10.1, R11.1, U2.12 (MTCK)
/Leds/LED_DATA_5V: R12.1, R13.1; also elsewhere on the board
/MCU_RX: J2.5 (TX), U2.27 (U0RXD)
/MCU_TX: J2.6 (RX), R8.1
/MODE_BUTTON: S1.2 (B), U2.6 (GPIO2)
/POWER_BUTTON: S3.2 (B), U2.8 (GPIO3)
/Reset: C11.1, J2.3 (Reset), R3.2, U2.7 (CHIP_EN)
/SERVER_LED: D9.2, R14.2, U2.9 (MTMS)
/USB_D+: J1.A6 (D+), J1.B6 (D+), U2.26 (GPIO19/USB_D+)
/USB_D-: J1.A7 (D-), J1.B7 (D-), U2.25 (GPIO18/USB_D-)
/WIFI_LED: D10.2, R15.2, U2.10 (MTDI)
GND: AE1.2 (Shield), C1.1, C2.1, C3.1, C4.1, C5.1, C6.2, C7.2, C8.2, C9.2, C10.2, C11.2, C12.2, C13.2, C14.2, C15.2, C16.1, C17.2, C18.2, C19.2, C20.2, C21.2, D3.2, D4.2, D5.2, D6.1, J1.A12B1 (GND), J1.B12A1 (GND), J1.S1 (SHIELD), J2.2 (GND), J2.7 (GND), Q2.2 (E), R1.2, R6.1, R7.2, R11.2, R13.2, R16.2, R17.2, S1.3 (C), S1.4 (D), S2.3 (C), S2.4 (D), S3.3 (C), S3.4 (D), S4.3 (C), S4.4 (D), U1.2 (GND), U2.33 (GND), U3.3 (GND), X1.2 (GND), X1.4 (GND); also elsewhere on the board
unnamed: AE1.1 (A), C19.1, D6.2, L2.2
unnamed: C5.2, D2.2, F1.1, J1.A9B4 (VBUS), J1.B9A4 (VBUS)
unnamed: C17.1, L1.1, X1.1 (OSC)
unnamed: D1.1, R1.1
unnamed: D2.1, R2.2
unnamed: D7.1, R14.1
unnamed: D8.1, R15.1
unnamed: D9.1, R16.1
unnamed: D10.1, R17.1
unnamed: J1.A5 (CC1), R7.1
unnamed: J1.B5 (CC2), R6.2
unnamed: Q1.1 (G), Q2.3 (C), R9.2
unnamed: C14.1, Q2.1 (B), R10.2
unnamed: C13.1, U2.18 ((OUTPUT)_VDD_SPI)
unnamed: R8.2, U2.28 (U0TXD)
unnamed: C16.2, U2.29 (XTAL_N), X1.3 (OSC)
unnamed: L1.2, U2.30 (XTAL_P)
unnamed: R12.2, U3.4 (Y)
VBUS: C10.1, C12.1, C20.1, C21.1, D4.1, F1.2, Q1.3 (D), R2.1, R9.1, U1.1 (VIN), U1.3 (EN), U3.5 (VCC)

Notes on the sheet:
These caps should be placed near level shifter
Charlieplexed status leds
Allows MCU to shut off power to 5V rail (leds)
Power LEDs (hardwired) Green = Power on Red = Polyfuse activated
Server
WiFi

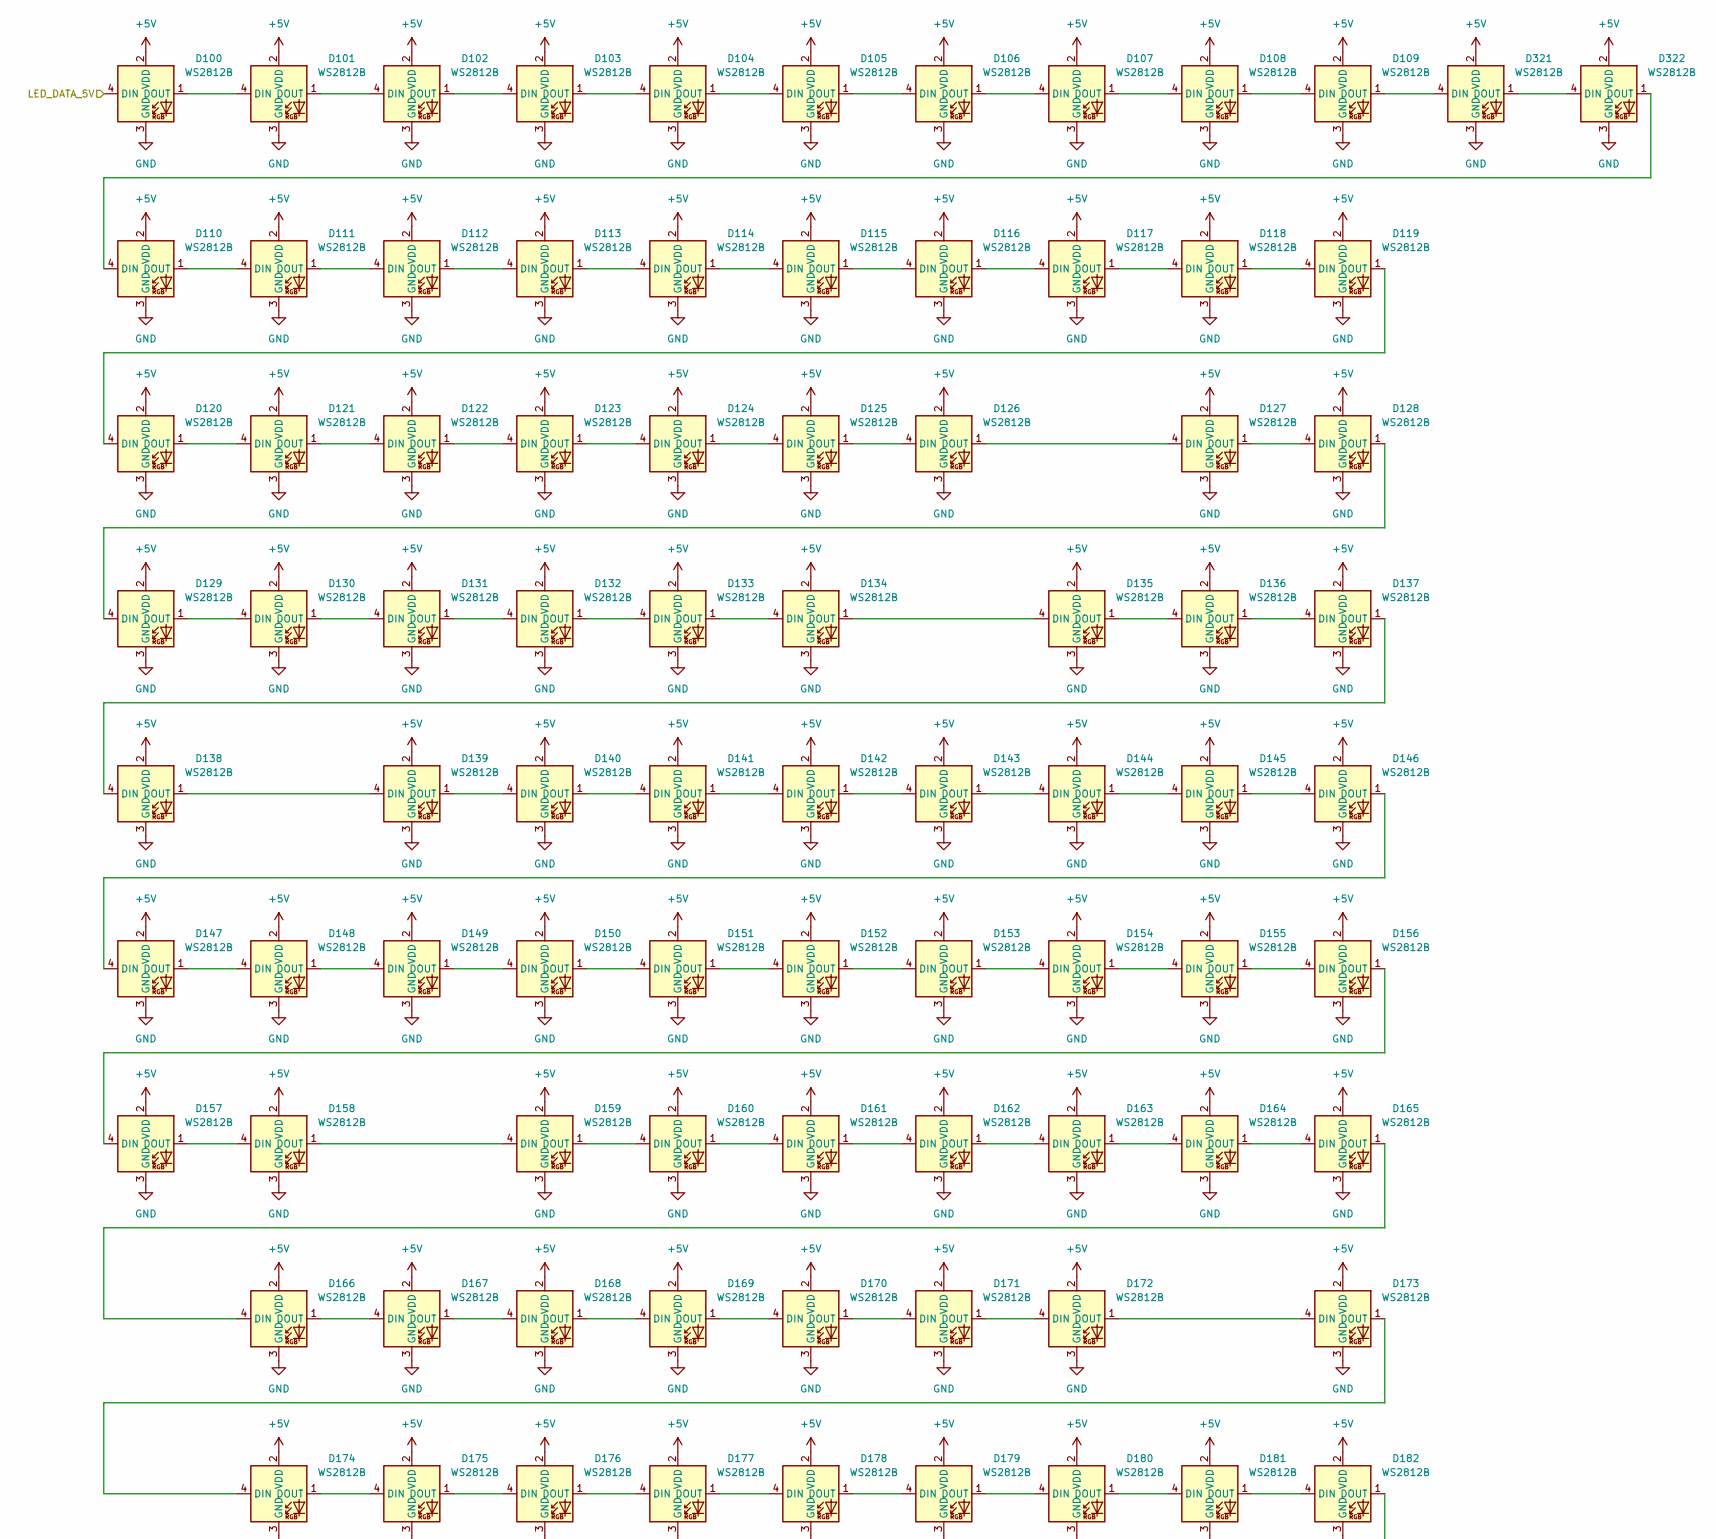
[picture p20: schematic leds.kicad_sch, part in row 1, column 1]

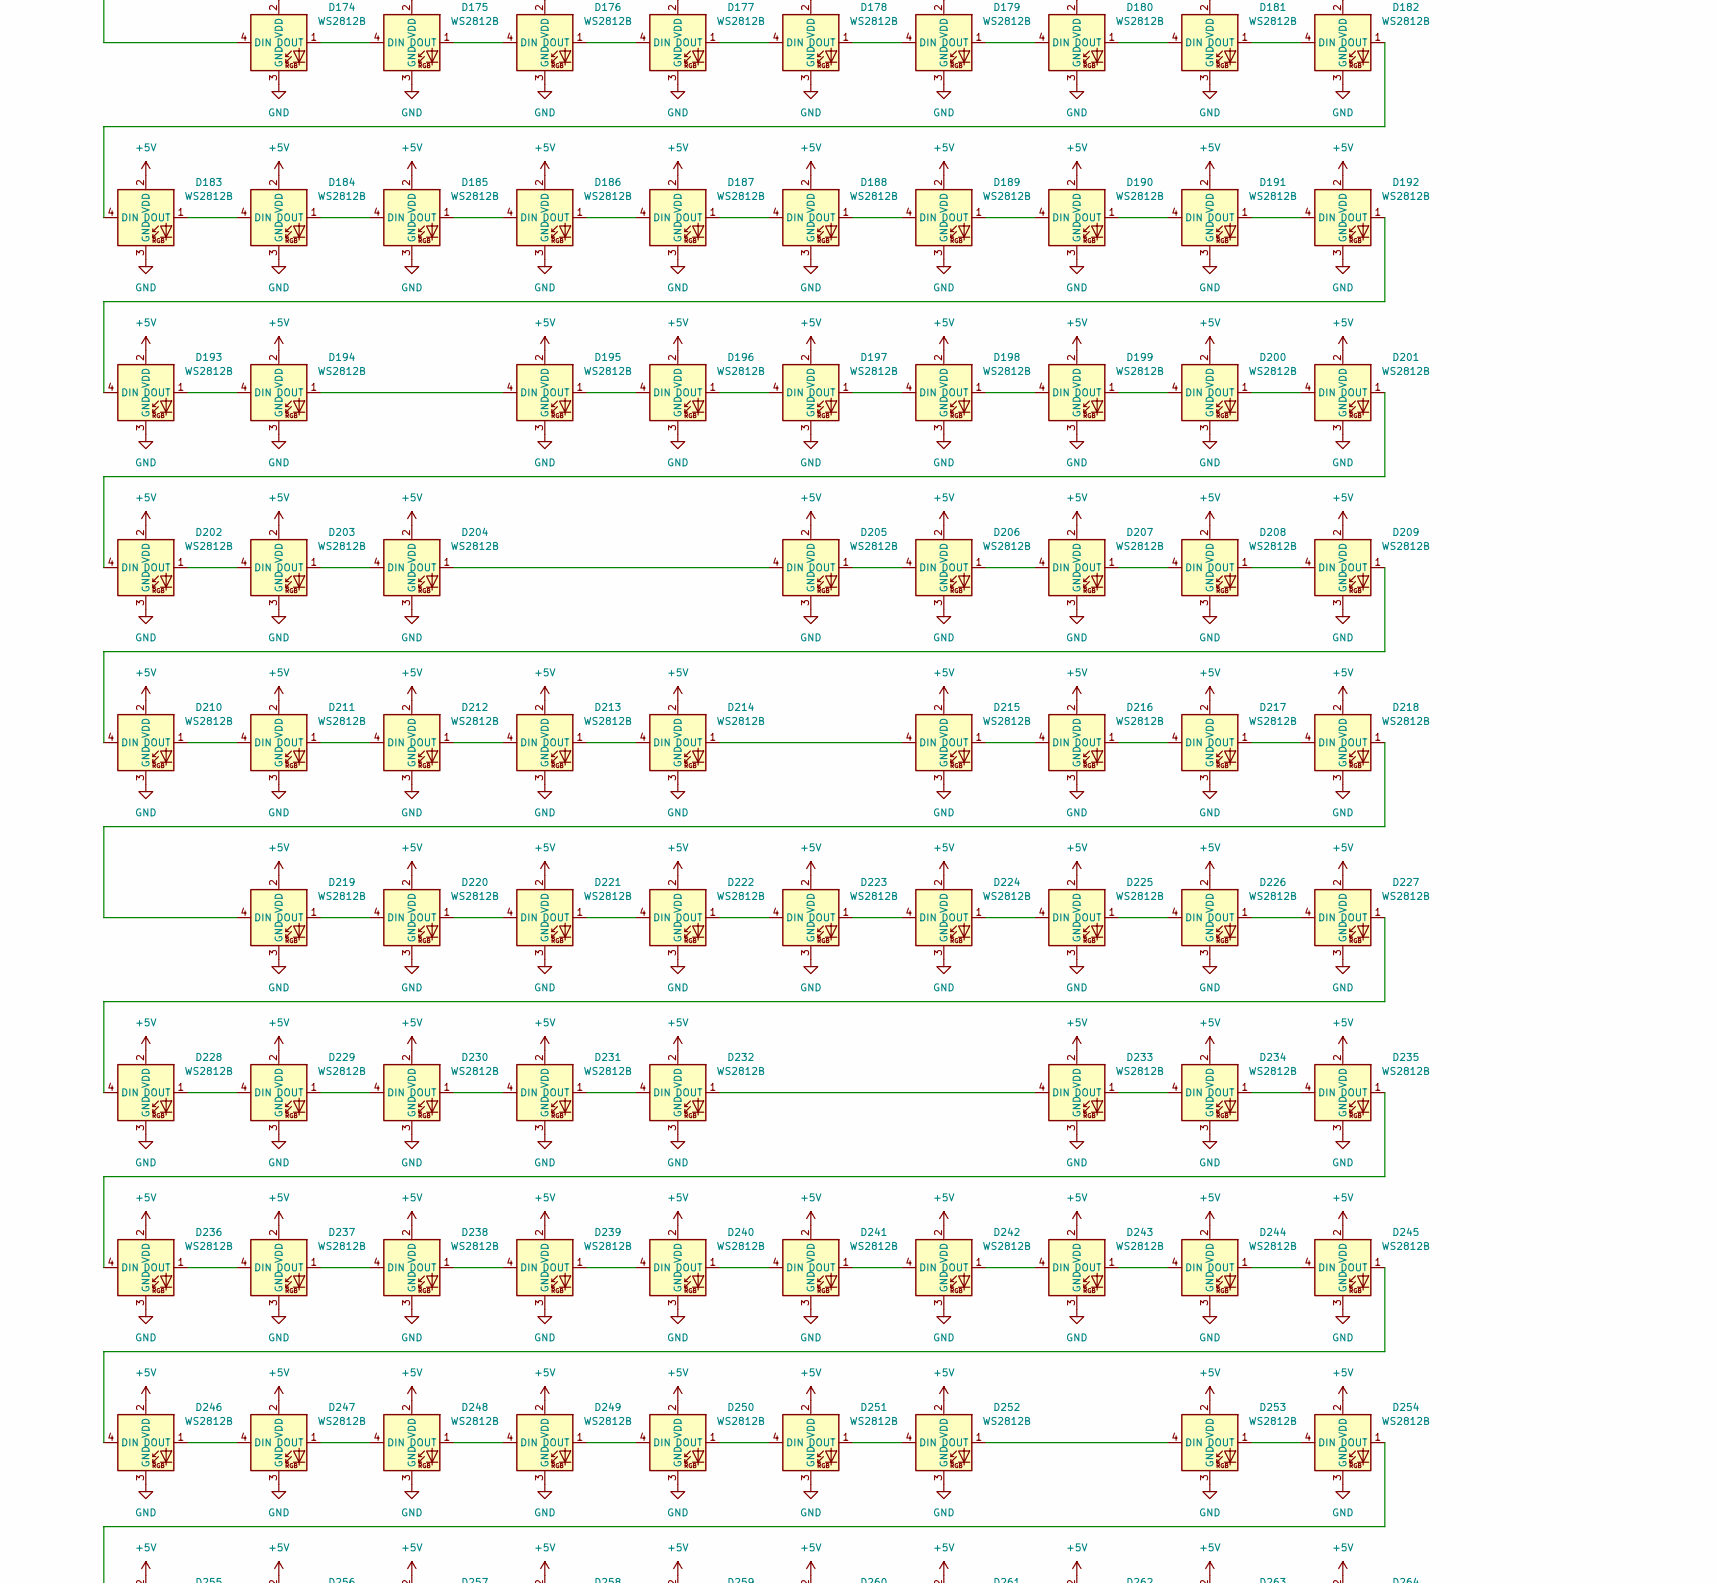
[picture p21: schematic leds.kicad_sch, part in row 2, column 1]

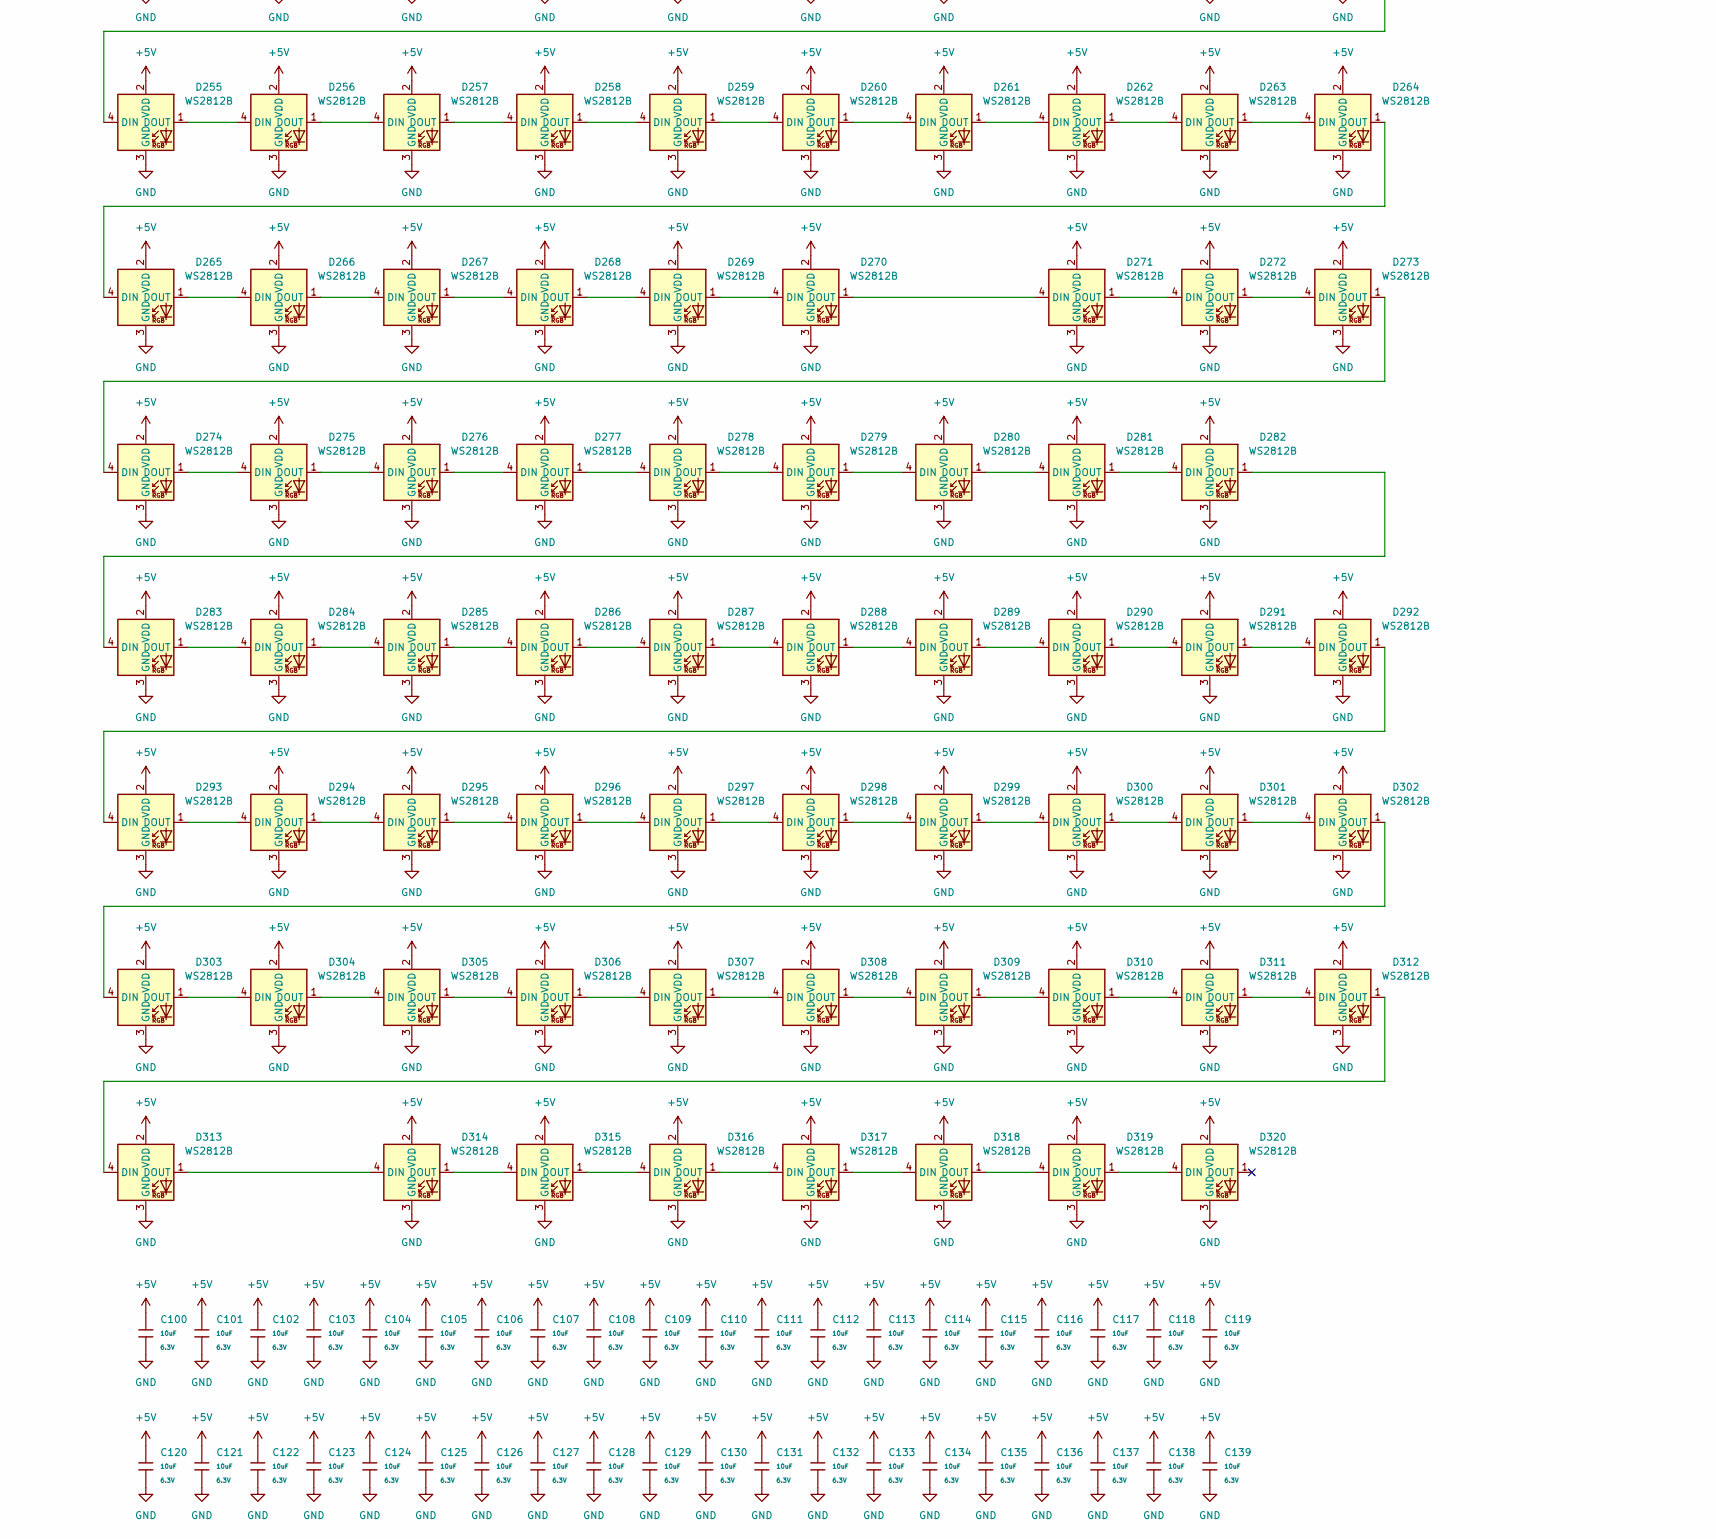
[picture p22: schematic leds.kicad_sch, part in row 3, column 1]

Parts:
C100, C101, C102, C103, C104, C105, C106, C107, C108, C109, C110, C111, C112, C113, C114, C115, C116, C117, C118, C119, C120, C121, C122, C123, C124, C125, C126, C127, C128, C129, C130, C131, C132, C133, C134, C135, C136, C137, C138, C139: 10uF; C_0402; Voltage Rated 6.3V; Tolerance ±20%; Part CL05A106MQ5NUNC; LCSC C15525
D100, D101, D102, D103, D104, D105, D106, D107, D108, D109, D110, D111, D112, D113, D114, D115, D116, D117, D118, D119, D120, D121, D122, D123, D124, D125, D126, D127, D128, D129, D130, D131, D132, D133, D134, D135, D136, D137, D138, D139, D140, D141, D142, D143, D144, D145, D146, D147, D148, D149, D150, D151, D152, D153, D154, D155, D156, D157, D158, D159, D160, D161, D162, D163, D164, D165, D166, D167, D168, D169, D170, D171, D172, D173, D174, D175, D176, D177, D178, D179, D180, D181, D182, D183, D184, D185, D186, D187, D188, D189, D190, D191, D192, D193, D194, D195, D196, D197, D198, D199, D200, D201, D202, D203, D204, D205, D206, D207, D208, D209, D210, D211, D212, D213, D214, D215, D216, D217, D218, D219, D220, D221, D222, D223, D224, D225, D226, D227, D228, D229, D230, D231, D232, D233, D234, D235, D236, D237, D238, D239, D240, D241, D242, D243, D244, D245, D246, D247, D248, D249, D250, D251, D252, D253, D254, D255, D256, D257, D258, D259, D260, D261, D262, D263, D264, D265, D266, D267, D268, D269, D270, D271, D272, D273, D274, D275, D276, D277, D278, D279, D280, D281, D282, D283, D284, D285, D286, D287, D288, D289, D290, D291, D292, D293, D294, D295, D296, D297, D298, D299, D300, D301, D302, D303, D304, D305, D306, D307, D308, D309, D310, D311, D312, D313, D314, D315, D316, D317, D318, D319, D320, D321, D322: WS2812B; LED-SMD_4P-L1.6-W1.5_XL-1615RGBC-WS2812B; LCSC C5349954

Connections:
+5V: C100.1, C101.1, C102.1, C103.1, C104.1, C105.1, C106.1, C107.1, C108.1, C109.1, C110.1, C111.1, C112.1, C113.1, C114.1, C115.1, C116.1, C117.1, C118.1, C119.1, C120.1, C121.1, C122.1, C123.1, C124.1, C125.1, C126.1, C127.1, C128.1, C129.1, C130.1, C131.1, C132.1, C133.1, C134.1, C135.1, C136.1, C137.1, C138.1, C139.1, D100.2 (VDD), D101.2 (VDD), D102.2 (VDD), D103.2 (VDD), D104.2 (VDD), D105.2 (VDD), D106.2 (VDD), D107.2 (VDD), D108.2 (VDD), D109.2 (VDD), D110.2 (VDD), D111.2 (VDD), D112.2 (VDD), D113.2 (VDD), D114.2 (VDD), D115.2 (VDD), D116.2 (VDD), D117.2 (VDD), D118.2 (VDD), D119.2 (VDD), D120.2 (VDD), D121.2 (VDD), D122.2 (VDD), D123.2 (VDD), D124.2 (VDD), D125.2 (VDD), D126.2 (VDD), D127.2 (VDD), D128.2 (VDD), D129.2 (VDD), D130.2 (VDD), D131.2 (VDD), D132.2 (VDD), D133.2 (VDD), D134.2 (VDD), D135.2 (VDD), D136.2 (VDD), D137.2 (VDD), D138.2 (VDD), D139.2 (VDD), D140.2 (VDD), D141.2 (VDD), D142.2 (VDD), D143.2 (VDD), D144.2 (VDD), D145.2 (VDD), D146.2 (VDD), D147.2 (VDD), D148.2 (VDD), D149.2 (VDD), D150.2 (VDD), D151.2 (VDD), D152.2 (VDD), D153.2 (VDD), D154.2 (VDD), D155.2 (VDD), D156.2 (VDD), D157.2 (VDD), D158.2 (VDD), D159.2 (VDD), D160.2 (VDD), D161.2 (VDD), D162.2 (VDD), D163.2 (VDD), D164.2 (VDD), D165.2 (VDD), D166.2 (VDD), D167.2 (VDD), D168.2 (VDD), D169.2 (VDD), D170.2 (VDD), D171.2 (VDD), D172.2 (VDD), D173.2 (VDD), D174.2 (VDD), D175.2 (VDD), D176.2 (VDD), D177.2 (VDD), D178.2 (VDD), D179.2 (VDD), D180.2 (VDD), D181.2 (VDD), D182.2 (VDD), D183.2 (VDD), D184.2 (VDD), D185.2 (VDD), D186.2 (VDD), D187.2 (VDD), D188.2 (VDD), D189.2 (VDD), D190.2 (VDD), D191.2 (VDD), D192.2 (VDD), D193.2 (VDD), D194.2 (VDD), D195.2 (VDD), D196.2 (VDD), D197.2 (VDD), D198.2 (VDD), D199.2 (VDD), D200.2 (VDD), D201.2 (VDD), D202.2 (VDD), D203.2 (VDD), D204.2 (VDD), D205.2 (VDD), D206.2 (VDD), D207.2 (VDD), D208.2 (VDD), D209.2 (VDD), D210.2 (VDD), D211.2 (VDD), D212.2 (VDD), D213.2 (VDD), D214.2 (VDD), D215.2 (VDD), D216.2 (VDD), D217.2 (VDD), D218.2 (VDD), D219.2 (VDD), D220.2 (VDD), D221.2 (VDD), D222.2 (VDD), D223.2 (VDD), D224.2 (VDD), D225.2 (VDD), D226.2 (VDD), D227.2 (VDD), D228.2 (VDD), D229.2 (VDD), D230.2 (VDD), D231.2 (VDD), D232.2 (VDD), D233.2 (VDD), D234.2 (VDD), D235.2 (VDD), D236.2 (VDD), D237.2 (VDD), D238.2 (VDD), D239.2 (VDD), D240.2 (VDD), D241.2 (VDD), D242.2 (VDD), D243.2 (VDD), D244.2 (VDD), D245.2 (VDD), D246.2 (VDD), D247.2 (VDD), D248.2 (VDD), D249.2 (VDD), D250.2 (VDD), D251.2 (VDD), D252.2 (VDD), D253.2 (VDD), D254.2 (VDD), D255.2 (VDD), D256.2 (VDD), D257.2 (VDD), D258.2 (VDD), D259.2 (VDD), D260.2 (VDD), D261.2 (VDD), D262.2 (VDD), D263.2 (VDD), D264.2 (VDD), D265.2 (VDD), D266.2 (VDD), D267.2 (VDD), D268.2 (VDD), D269.2 (VDD), D270.2 (VDD), D271.2 (VDD), D272.2 (VDD), D273.2 (VDD), D274.2 (VDD), D275.2 (VDD), D276.2 (VDD), D277.2 (VDD), D278.2 (VDD), D279.2 (VDD), D280.2 (VDD)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; also elsewhere on the board
/Leds/LED_DATA_5V: D100.4 (DIN); also elsewhere on the board
GND: C100.2, C101.2, C102.2, C103.2, C104.2, C105.2, C106.2, C107.2, C108.2, C109.2, C110.2, C111.2, C112.2, C113.2, C114.2, C115.2, C116.2, C117.2, C118.2, C119.2, C120.2, C121.2, C122.2, C123.2, C124.2, C125.2, C126.2, C127.2, C128.2, C129.2, C130.2, C131.2, C132.2, C133.2, C134.2, C135.2, C136.2, C137.2, C138.2, C139.2, D100.3 (GND), D101.3 (GND), D102.3 (GND), D103.3 (GND), D104.3 (GND), D105.3 (GND), D106.3 (GND), D107.3 (GND), D108.3 (GND), D109.3 (GND), D110.3 (GND), D111.3 (GND), D112.3 (GND), D113.3 (GND), D114.3 (GND), D115.3 (GND), D116.3 (GND), D117.3 (GND), D118.3 (GND), D119.3 (GND), D120.3 (GND), D121.3 (GND), D122.3 (GND), D123.3 (GND), D124.3 (GND), D125.3 (GND), D126.3 (GND), D127.3 (GND), D128.3 (GND), D129.3 (GND), D130.3 (GND), D131.3 (GND), D132.3 (GND), D133.3 (GND), D134.3 (GND), D135.3 (GND), D136.3 (GND), D137.3 (GND), D138.3 (GND), D139.3 (GND), D140.3 (GND), D141.3 (GND), D142.3 (GND), D143.3 (GND), D144.3 (GND), D145.3 (GND), D146.3 (GND), D147.3 (GND), D148.3 (GND), D149.3 (GND), D150.3 (GND), D151.3 (GND), D152.3 (GND), D153.3 (GND), D154.3 (GND), D155.3 (GND), D156.3 (GND), D157.3 (GND), D158.3 (GND), D159.3 (GND), D160.3 (GND), D161.3 (GND), D162.3 (GND), D163.3 (GND), D164.3 (GND), D165.3 (GND), D166.3 (GND), D167.3 (GND), D168.3 (GND), D169.3 (GND), D170.3 (GND), D171.3 (GND), D172.3 (GND), D173.3 (GND), D174.3 (GND), D175.3 (GND), D176.3 (GND), D177.3 (GND), D178.3 (GND), D179.3 (GND), D180.3 (GND), D181.3 (GND), D182.3 (GND), D183.3 (GND), D184.3 (GND), D185.3 (GND), D186.3 (GND), D187.3 (GND), D188.3 (GND), D189.3 (GND), D190.3 (GND), D191.3 (GND), D192.3 (GND), D193.3 (GND), D194.3 (GND), D195.3 (GND), D196.3 (GND), D197.3 (GND), D198.3 (GND), D199.3 (GND), D200.3 (GND), D201.3 (GND), D202.3 (GND), D203.3 (GND), D204.3 (GND), D205.3 (GND), D206.3 (GND), D207.3 (GND), D208.3 (GND), D209.3 (GND), D210.3 (GND), D211.3 (GND), D212.3 (GND), D213.3 (GND), D214.3 (GND), D215.3 (GND), D216.3 (GND), D217.3 (GND), D218.3 (GND), D219.3 (GND), D220.3 (GND), D221.3 (GND), D222.3 (GND), D223.3 (GND), D224.3 (GND), D225.3 (GND), D226.3 (GND), D227.3 (GND), D228.3 (GND), D229.3 (GND), D230.3 (GND), D231.3 (GND), D232.3 (GND), D233.3 (GND), D234.3 (GND), D235.3 (GND), D236.3 (GND), D237.3 (GND), D238.3 (GND), D239.3 (GND), D240.3 (GND), D241.3 (GND), D242.3 (GND), D243.3 (GND), D244.3 (GND), D245.3 (GND), D246.3 (GND), D247.3 (GND), D248.3 (GND), D249.3 (GND), D250.3 (GND), D251.3 (GND), D252.3 (GND), D253.3 (GND), D254.3 (GND), D255.3 (GND), D256.3 (GND), D257.3 (GND), D258.3 (GND), D259.3 (GND), D260.3 (GND), D261.3 (GND), D262.3 (GND), D263.3 (GND), D264.3 (GND), D265.3 (GND), D266.3 (GND), D267.3 (GND), D268.3 (GND), D269.3 (GND), D270.3 (GND), D271.3 (GND), D272.3 (GND), D273.3 (GND), D274.3 (GND), D275.3 (GND), D276.3 (GND), D277.3 (GND), D278.3 (GND), D279.3 (GND), D280.3 (GND)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; also elsewhere on the board
unnamed: D100.1 (DOUT), D101.4 (DIN)
unnamed: D101.1 (DOUT), D102.4 (DIN)
unnamed: D102.1 (DOUT), D103.4 (DIN)
unnamed: D103.1 (DOUT), D104.4 (DIN)
unnamed: D104.1 (DOUT), D105.4 (DIN)
unnamed: D105.1 (DOUT), D106.4 (DIN)
unnamed: D106.1 (DOUT), D107.4 (DIN)
unnamed: D107.1 (DOUT), D108.4 (DIN)
unnamed: D108.1 (DOUT), D109.4 (DIN)
unnamed: D109.1 (DOUT), D321.4 (DIN)
unnamed: D110.4 (DIN), D322.1 (DOUT)
unnamed: D110.1 (DOUT), D111.4 (DIN)
unnamed: D111.1 (DOUT), D112.4 (DIN)
unnamed: D112.1 (DOUT), D113.4 (DIN)
unnamed: D113.1 (DOUT), D114.4 (DIN)
unnamed: D114.1 (DOUT), D115.4 (DIN)
unnamed: D115.1 (DOUT), D116.4 (DIN)
unnamed: D116.1 (DOUT), D117.4 (DIN)
unnamed: D117.1 (DOUT), D118.4 (DIN)
unnamed: D118.1 (DOUT), D119.4 (DIN)
unnamed: D119.1 (DOUT), D120.4 (DIN)
unnamed: D120.1 (DOUT), D121.4 (DIN)
unnamed: D121.1 (DOUT), D122.4 (DIN)
unnamed: D122.1 (DOUT), D123.4 (DIN)
unnamed: D123.1 (DOUT), D124.4 (DIN)
unnamed: D124.1 (DOUT), D125.4 (DIN)
unnamed: D125.1 (DOUT), D126.4 (DIN)
unnamed: D126.1 (DOUT), D127.4 (DIN)
unnamed: D127.1 (DOUT), D128.4 (DIN)
unnamed: D128.1 (DOUT), D129.4 (DIN)
unnamed: D129.1 (DOUT), D130.4 (DIN)
unnamed: D130.1 (DOUT), D131.4 (DIN)
unnamed: D131.1 (DOUT), D132.4 (DIN)
unnamed: D132.1 (DOUT), D133.4 (DIN)
unnamed: D133.1 (DOUT), D134.4 (DIN)
unnamed: D134.1 (DOUT), D135.4 (DIN)
unnamed: D135.1 (DOUT), D136.4 (DIN)
unnamed: D136.1 (DOUT), D137.4 (DIN)
unnamed: D137.1 (DOUT), D138.4 (DIN)
unnamed: D138.1 (DOUT), D139.4 (DIN)
unnamed: D139.1 (DOUT), D140.4 (DIN)
unnamed: D140.1 (DOUT), D141.4 (DIN)
unnamed: D141.1 (DOUT), D142.4 (DIN)
unnamed: D142.1 (DOUT), D143.4 (DIN)
unnamed: D143.1 (DOUT), D144.4 (DIN)
unnamed: D144.1 (DOUT), D145.4 (DIN)
unnamed: D145.1 (DOUT), D146.4 (DIN)
unnamed: D146.1 (DOUT), D147.4 (DIN)
unnamed: D147.1 (DOUT), D148.4 (DIN)
unnamed: D148.1 (DOUT), D149.4 (DIN)
unnamed: D149.1 (DOUT), D150.4 (DIN)
unnamed: D150.1 (DOUT), D151.4 (DIN)
unnamed: D151.1 (DOUT), D152.4 (DIN)
unnamed: D152.1 (DOUT), D153.4 (DIN)
unnamed: D153.1 (DOUT), D154.4 (DIN)
unnamed: D154.1 (DOUT), D155.4 (DIN)
unnamed: D155.1 (DOUT), D156.4 (DIN)
unnamed: D156.1 (DOUT), D157.4 (DIN)
unnamed: D157.1 (DOUT), D158.4 (DIN)
unnamed: D158.1 (DOUT), D159.4 (DIN)
unnamed: D159.1 (DOUT), D160.4 (DIN)
unnamed: D160.1 (DOUT), D161.4 (DIN)
unnamed: D161.1 (DOUT), D162.4 (DIN)
unnamed: D162.1 (DOUT), D163.4 (DIN)
unnamed: D163.1 (DOUT), D164.4 (DIN)
unnamed: D164.1 (DOUT), D165.4 (DIN)
unnamed: D165.1 (DOUT), D166.4 (DIN)
unnamed: D166.1 (DOUT), D167.4 (DIN)
unnamed: D167.1 (DOUT), D168.4 (DIN)
unnamed: D168.1 (DOUT), D169.4 (DIN)
unnamed: D169.1 (DOUT), D170.4 (DIN)
unnamed: D170.1 (DOUT), D171.4 (DIN)
unnamed: D171.1 (DOUT), D172.4 (DIN)
unnamed: D172.1 (DOUT), D173.4 (DIN)
unnamed: D173.1 (DOUT), D174.4 (DIN)
unnamed: D174.1 (DOUT), D175.4 (DIN)
unnamed: D175.1 (DOUT), D176.4 (DIN)
unnamed: D176.1 (DOUT), D177.4 (DIN)
unnamed: D177.1 (DOUT), D178.4 (DIN)
unnamed: D178.1 (DOUT), D179.4 (DIN)
unnamed: D179.1 (DOUT), D180.4 (DIN)
unnamed: D180.1 (DOUT), D181.4 (DIN)
unnamed: D181.1 (DOUT), D182.4 (DIN)
unnamed: D182.1 (DOUT), D183.4 (DIN)
unnamed: D183.1 (DOUT), D184.4 (DIN)
unnamed: D184.1 (DOUT), D185.4 (DIN)
unnamed: D185.1 (DOUT), D186.4 (DIN)
unnamed: D186.1 (DOUT), D187.4 (DIN)
unnamed: D187.1 (DOUT), D188.4 (DIN)
unnamed: D188.1 (DOUT), D189.4 (DIN)
unnamed: D189.1 (DOUT), D190.4 (DIN)
unnamed: D190.1 (DOUT), D191.4 (DIN)
unnamed: D191.1 (DOUT), D192.4 (DIN)
unnamed: D192.1 (DOUT), D193.4 (DIN)
unnamed: D193.1 (DOUT), D194.4 (DIN)
unnamed: D194.1 (DOUT), D195.4 (DIN)
unnamed: D195.1 (DOUT), D196.4 (DIN)
unnamed: D196.1 (DOUT), D197.4 (DIN)
unnamed: D197.1 (DOUT), D198.4 (DIN)
unnamed: D198.1 (DOUT), D199.4 (DIN)
unnamed: D199.1 (DOUT), D200.4 (DIN)
unnamed: D200.1 (DOUT), D201.4 (DIN)
unnamed: D201.1 (DOUT), D202.4 (DIN)
unnamed: D202.1 (DOUT), D203.4 (DIN)
unnamed: D203.1 (DOUT), D204.4 (DIN)
unnamed: D204.1 (DOUT), D205.4 (DIN)
unnamed: D205.1 (DOUT), D206.4 (DIN)
unnamed: D206.1 (DOUT), D207.4 (DIN)
unnamed: D207.1 (DOUT), D208.4 (DIN)
unnamed: D208.1 (DOUT), D209.4 (DIN)
unnamed: D209.1 (DOUT), D210.4 (DIN)
unnamed: D210.1 (DOUT), D211.4 (DIN)
unnamed: D211.1 (DOUT), D212.4 (DIN)
unnamed: D212.1 (DOUT), D213.4 (DIN)
unnamed: D213.1 (DOUT), D214.4 (DIN)
unnamed: D214.1 (DOUT), D215.4 (DIN)
unnamed: D215.1 (DOUT), D216.4 (DIN)
unnamed: D216.1 (DOUT), D217.4 (DIN)
unnamed: D217.1 (DOUT), D218.4 (DIN)
unnamed: D218.1 (DOUT), D219.4 (DIN)
unnamed: D219.1 (DOUT), D220.4 (DIN)
unnamed: D220.1 (DOUT), D221.4 (DIN)
unnamed: D221.1 (DOUT), D222.4 (DIN)
unnamed: D222.1 (DOUT), D223.4 (DIN)
unnamed: D223.1 (DOUT), D224.4 (DIN)
unnamed: D224.1 (DOUT), D225.4 (DIN)
unnamed: D225.1 (DOUT), D226.4 (DIN)
unnamed: D226.1 (DOUT), D227.4 (DIN)
unnamed: D227.1 (DOUT), D228.4 (DIN)
unnamed: D228.1 (DOUT), D229.4 (DIN)
unnamed: D229.1 (DOUT), D230.4 (DIN)
unnamed: D230.1 (DOUT), D231.4 (DIN)
unnamed: D231.1 (DOUT), D232.4 (DIN)
unnamed: D232.1 (DOUT), D233.4 (DIN)
unnamed: D233.1 (DOUT), D234.4 (DIN)
unnamed: D234.1 (DOUT), D235.4 (DIN)
unnamed: D235.1 (DOUT), D236.4 (DIN)
unnamed: D236.1 (DOUT), D237.4 (DIN)
unnamed: D237.1 (DOUT), D238.4 (DIN)
unnamed: D238.1 (DOUT), D239.4 (DIN)
unnamed: D239.1 (DOUT), D240.4 (DIN)
unnamed: D240.1 (DOUT), D241.4 (DIN)
unnamed: D241.1 (DOUT), D242.4 (DIN)
unnamed: D242.1 (DOUT), D243.4 (DIN)
unnamed: D243.1 (DOUT), D244.4 (DIN)
unnamed: D244.1 (DOUT), D245.4 (DIN)
unnamed: D245.1 (DOUT), D246.4 (DIN)
unnamed: D246.1 (DOUT), D247.4 (DIN)
unnamed: D247.1 (DOUT), D248.4 (DIN)
unnamed: D248.1 (DOUT), D249.4 (DIN)
unnamed: D249.1 (DOUT), D250.4 (DIN)
unnamed: D250.1 (DOUT), D251.4 (DIN)
unnamed: D251.1 (DOUT), D252.4 (DIN)
unnamed: D252.1 (DOUT), D253.4 (DIN)
unnamed: D253.1 (DOUT), D254.4 (DIN)
unnamed: D254.1 (DOUT), D255.4 (DIN)
unnamed: D255.1 (DOUT), D256.4 (DIN)
unnamed: D256.1 (DOUT), D257.4 (DIN)
unnamed: D257.1 (DOUT), D258.4 (DIN)
unnamed: D258.1 (DOUT), D259.4 (DIN)
unnamed: D259.1 (DOUT), D260.4 (DIN)
unnamed: D260.1 (DOUT), D261.4 (DIN)
unnamed: D261.1 (DOUT), D262.4 (DIN)
unnamed: D262.1 (DOUT), D263.4 (DIN)
unnamed: D263.1 (DOUT), D264.4 (DIN)
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

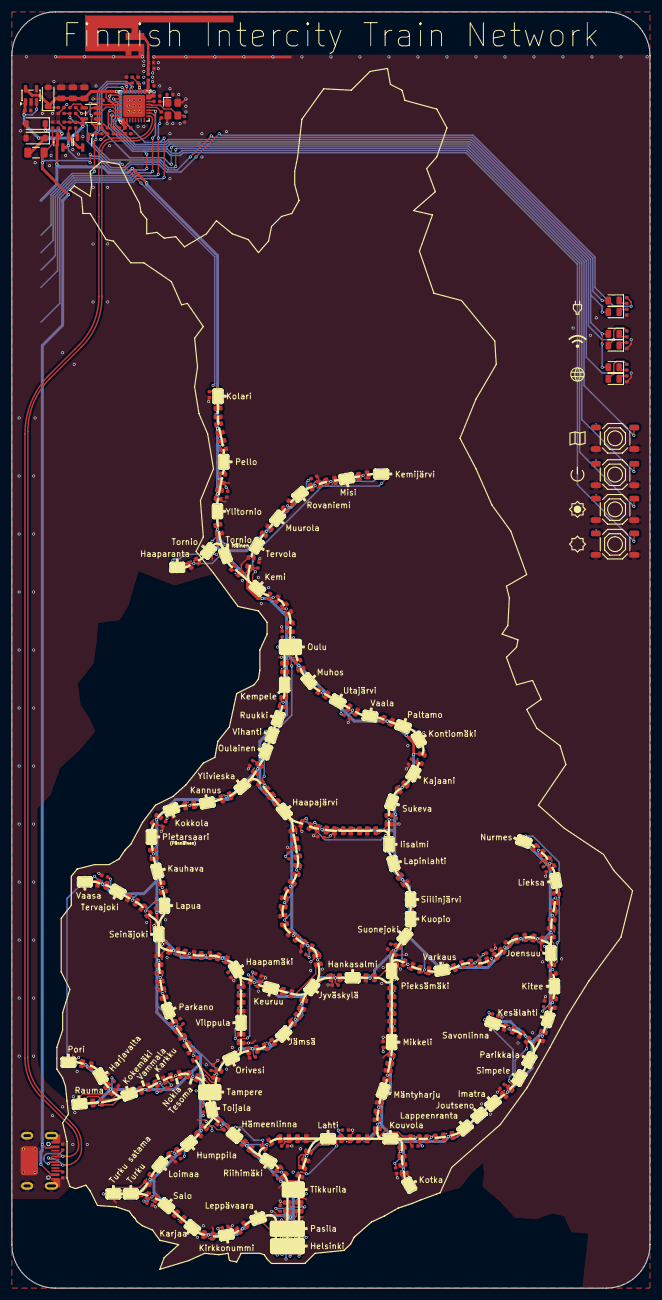
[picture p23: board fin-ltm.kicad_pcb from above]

Board: 2 copper layers, 110.0 x 220.0 mm, 327 parts (0 on the bottom side), 259 nets.

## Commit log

2026-04-19 initialized kicad project and started drawing schematic
    [hki-ltm.kicad_pcb, hki-ltm.kicad_sch]
2026-04-19 More schematic power system work
    [hki-ltm.kicad_sch, leds.kicad_sch]
2026-04-20 continued schematic
    [fin-ltm.kicad_pcb, fin-ltm.kicad_sch, hki-ltm.kicad_sch]
2026-04-20 Fixed ERC issues
    [fin-ltm.kicad_sch]
2026-04-21 schematic update
    [fin-ltm.kicad_sch]
2026-04-22 BOM check and small tweaks
    [fin-ltm.csv, fin-ltm.kicad_sch]
2026-04-30 Started adding leds and started making pcbs.
    [fin-ltm.kicad_pcb, fin-ltm.kicad_sch, leds.kicad_sch]
2026-04-30 server updates and battling with kicad
    [fin-ltm.kicad_pcb, fin-ltm.kicad_sch, leds.kicad_sch]
2026-05-03 pcb designed antenna
    [fin-ltm.kicad_pcb]
2026-05-04 pcb update and planning in svg
    [fin-ltm.kicad_pcb, fin-ltm.kicad_sch, leds.kicad_sch]
2026-05-04 more pcb routing
    [fin-ltm.kicad_pcb, fin-ltm.kicad_sch]
2026-05-04 even more pcb routing
    [fin-ltm.kicad_pcb]
2026-05-05 pcb 2
    [fin-ltm.kicad_pcb, fin-ltm.kicad_sch]
2026-05-05 pcb 3
2026-05-07 pcb tweaks
    [fin-ltm.kicad_pcb]
2026-05-08 add oled
    [fin-ltm.kicad_pcb, fin-ltm.kicad_sch]
2026-05-08 led routing
    [fin-ltm.kicad_pcb, fin-ltm.kicad_sch]
2026-05-08 finished pcb routing
    [leds.kicad_sch]
2026-05-28 overhauled pcb layout
    [fin-ltm-B_Cu.gbr, fin-ltm-B_Mask.gbr, fin-ltm-B_Paste.gbr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]
2026-05-28 Changing the silkscreen and changing led layout
    [fin-ltm.kicad_pcb, leds.kicad_sch]
2026-05-31 smol tweak
    [fin-ltm.kicad_pcb, leds.kicad_sch]
2026-06-01 tweaked layout
    [fin-ltm.kicad_pcb, leds.kicad_sch]
2026-06-01 smaller tweaks
    [fin-ltm.kicad_pcb, leds.kicad_sch]
2026-06-02 finished led placement
    [fin-ltm.kicad_pcb, leds.kicad_sch]
2026-06-02 moved usb traces
    [fin-ltm.kicad_pcb]
2026-06-03 pcb mostly done
    [fin-ltm.kicad_pcb]
2026-06-04 linking leds to stations
    [fin-ltm.kicad_pcb, fin-ltm.kicad_sch, leds.kicad_sch]
2026-06-04 kicad something??
2026-06-06 Changed pcb and exported 3d files
    [OnlyPcb.step, PCB+Components.step, fin-ltm.kicad_pcb]
2026-06-07 added led decoupling caps
    [fin-ltm.kicad_pcb, leds.kicad_sch]
2026-06-08 Changed spot of 3d files.
    [OnlyPcb.step, PCB+Components.step]
2026-06-08 pcb finished
    [fin-ltm.kicad_pcb, fin-ltm.kicad_sch]
2026-06-08 remove fill from zones
    [fin-ltm.kicad_pcb]
2026-06-08 readded fill
    [fin-ltm.kicad_pcb]
2026-06-08 added icons to pcb
    [fin-ltm.kicad_pcb]
2026-06-09 readme and pcb fixes
    [fin-ltm.kicad_pcb]
2026-06-09 pcb update
    [fin-ltm.kicad_pcb, leds.kicad_sch]
2026-06-09 wrote more definitions
    [fin-ltm.kicad_pcb, leds.kicad_sch]
2026-06-10 finished linking
    [fin-ltm.kicad_pcb]
2026-06-10 server update
    [fin-ltm.kicad_pcb]
2026-06-11 something pcb idk
    [fin-ltm.kicad_pcb]
2026-06-16 added haaparanta
    [fin-ltm.kicad_pcb, leds.kicad_sch]
2026-06-16 oops is forgot these
    [fin-ltm.kicad_pcb]
2026-06-17 finished pcb
    [fin-ltm.kicad_pcb, fin-ltm.kicad_sch]
2026-06-17 Add 3D files for wall mount.
    [PCBWallMount.3mf, PCBWallMount.step, PCBWallmountFullProject.f3d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]
2026-06-21 copied over the firmware
    [default_4MB.csv]
2026-06-24 capcitor fix
    [fin-ltm.kicad_pcb, fin-ltm.kicad_sch]
2026-06-24 3d files update
    [PCB+Components.step]
2026-06-25 Add jlcpcb manufacturing files.
    [BOM-fin-ltm.csv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]
2026-06-25 Add PCB order instructions
2026-06-25 fixed conflivt
    [BOM-fin-ltm.csv, PCB+Components.step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]
2026-06-25 fixing git issues
    [fin-ltm-B_Cu.gbr, fin-ltm-B_Mask.gbr, fin-ltm-B_Paste.gbr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]
2026-06-30 moved software to new repo
    [default_4MB.csv]
2026-07-17 Add blender render
    [fin-ltm.kicad_pcb, pcb.blend]
2026-07-18 Added more printing instructions.
2026-07-19 Added BOM info
2026-07-19 Add new full design files.
    [FullProject.step, PCBWallmountFullProject.f3d, PCBWallmountFullProject.step]
2026-07-19 Add new printable files.
    [WallMountMainBody.3mf, WallMountTopLeft.3mf, WallMountTopLeft.step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]
2026-07-19 Add BOM.csv.
    [BOM.csv]
2026-07-19 Add embedded bom.
2026-07-20 Update BOM
    [BOM.csv]
2026-08-27 add debug pin
    [fin-ltm.kicad_pcb, fin-ltm.kicad_sch, leds.kicad_sch]
2026-08-27 fix trace issues
    [fin-ltm.kicad_pcb]
